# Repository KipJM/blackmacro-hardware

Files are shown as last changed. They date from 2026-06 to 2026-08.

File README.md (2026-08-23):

# BMacro V2
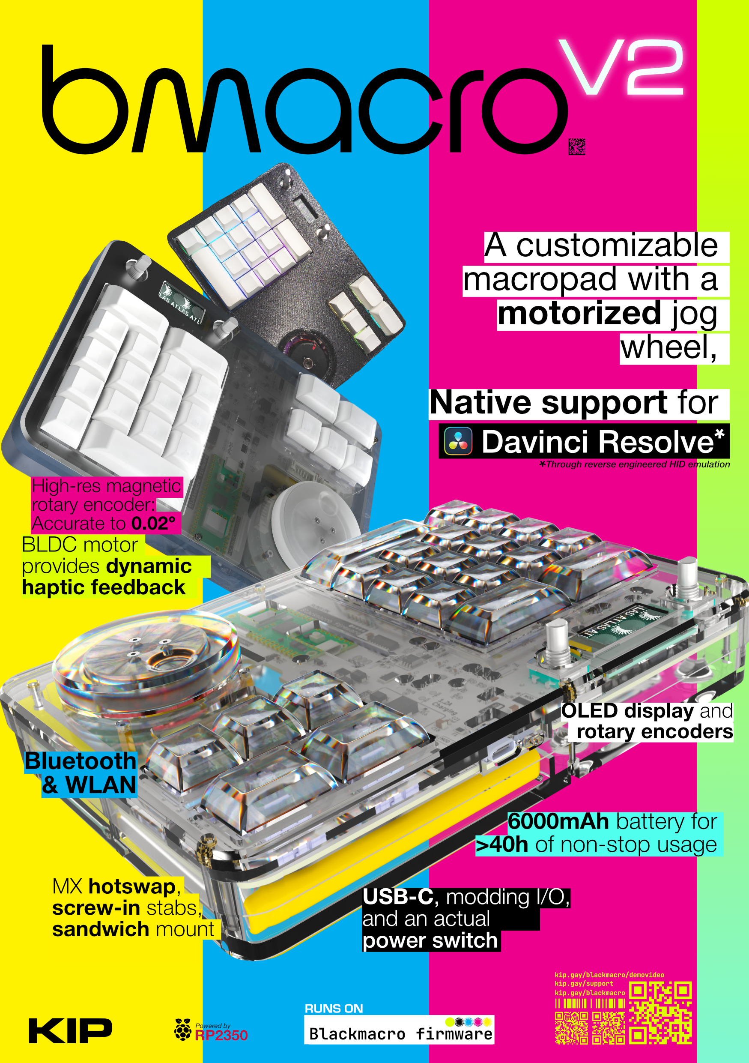
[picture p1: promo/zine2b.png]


> # This project took me over _*300*_ hours of work to create.
> Donations to my Ko-Fi would be highly appreciated! It'll support me to continue updating my project and its firmware.
> 
> ### **You can support me at: https://kip.gay/support**

> Additionally, if you're perhaps interested in purchasing an assembled blackmacro keyboard, let me know in github issues!
> I'd love to see if it's possible to mass manufacture this thing to bring costs down.

A bluetooth-capable condensed macro keyboard with a motorized jog wheel, powered by a Raspberry Pi Pico 2W.

### This keyboard's jog wheel gives you smooth analog control over the Davinci Resolve playhead, which is only possible on this keyboard or the official Speed Editor.

Supports remappable keyboard input, smooth scrolling, MIDI input, or
driverless Davinci Resolve control through reverse-engineered HID emulation.

Each key is a hotswappable MX-style plateless switch with a reverse-mounted addressable RGB LED.
The 2u and 1.5u in/out clips/timeline keys also feature screw-mount stabilizers.

The jog wheel is driven by a FOC-controlled brushless DC motor and a magnetic angle encoder, allowing for user-definable
haptic feedback and buttery smooth scrolling when working through your video timeline.

**It costs ~180 USD to create one blackmacro keyboard if not using CNC.**

> #### This hardware is purpose-built for blackmacro-lib. For more information on the purpose of this device, see [blackmacro-lib](https://github.com/KipJM/blackmacro-lib).
> #### For the firmware of this device, see [blackmacro-firmware](https://github.com/KipJM/blackmacro-firmware).

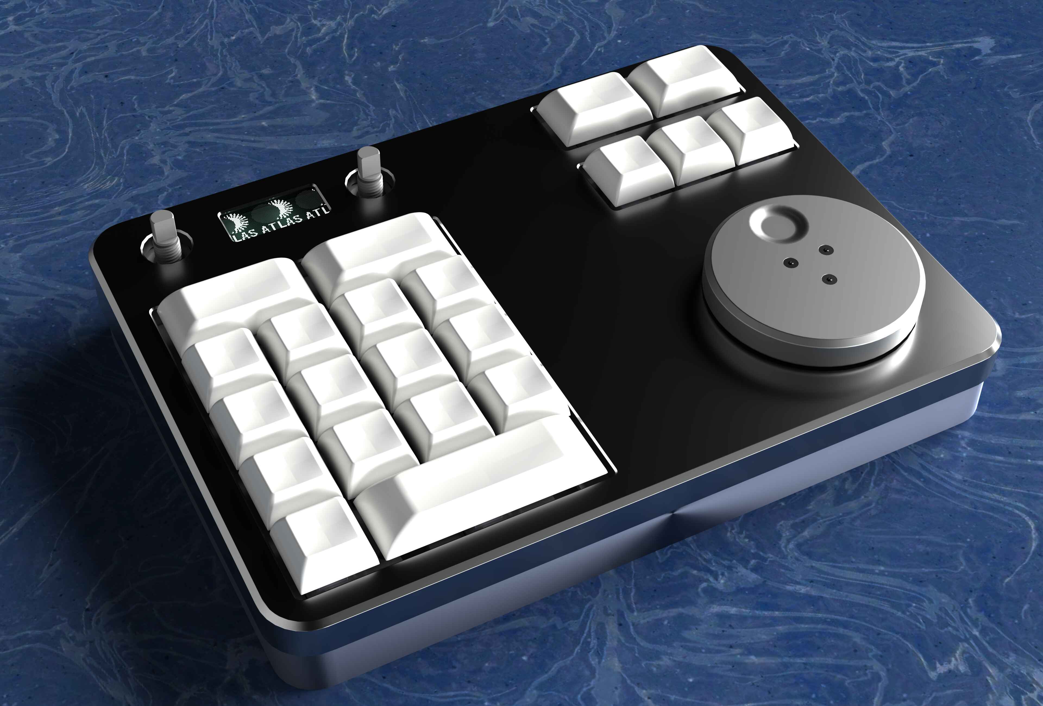
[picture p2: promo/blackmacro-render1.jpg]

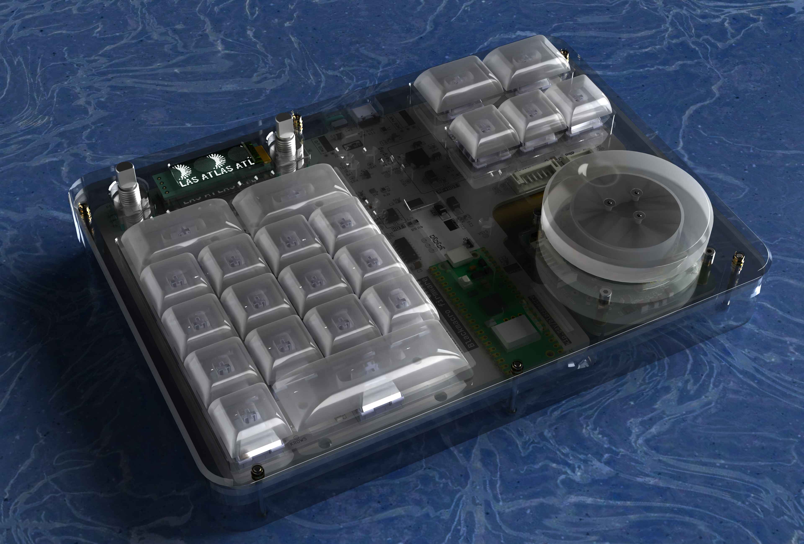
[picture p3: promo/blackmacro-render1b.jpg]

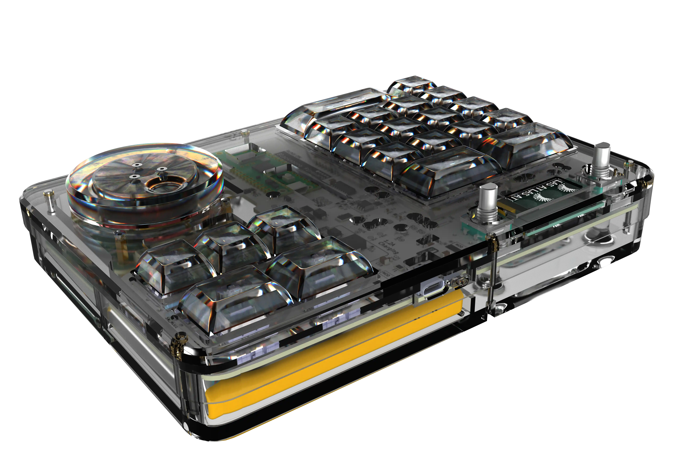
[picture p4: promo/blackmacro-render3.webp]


> ### Name
> Help me pick a better name for this thing...

> You're looking at version 2. For V1 archive switch to branch v1.

# Why
Bmacro (or Blackmacro keyboard) is designed to be an open source, leaner, customizable, and more powerful alternative to the Davinci Resolve Speed Editor keyboard.

The original speed editor features keys that aren't remappable and is locked to the Davinci Resolve software, only some of its keys feaure single-color LEDs,
plus its jog wheel doesn't feature the mechanical clutch found on its bigger Editor Keyboard sibling. Bmacro improves on this in almost every way, then adding
additional knobs to expand its input capabilities! While it features less keys than the Speed Editor, each key is software remappable so you can have the inputs you actually need.
Inspired by the smartknob project, the jog wheel is replaced with a Field Oriented Controlled BLDC motor, not only allowing it to emulate a mechanical clutch, but also other [software-defined haptic feedback!](https://www.youtube.com/watch?v=J9192DfZplk)

Running the FOSS Blackmacro firmware, bmacro can not only fully emulate all features of the Speed Editor and interface with Davinci Resolve without the need for any drivers,
but it can also emulate other inputs, such as smooth scrolling, volume control, generic macropad, or MIDI input. Through the rotary encoder knob and the 0.91 inch OLED screen, you can switch between these modes.

Demo Video (https://www.youtube.com/watch?v=7sNWoTAWSeA)

# License
This project is licensed under the CERN Open Hardware Licence Version 2 - Weakly Reciprocal.

Copyright © KIP 2026.

**Any individual or corporate entity are strictly forbidden from training "generative AI" analytical neural networks (LLMs, etc.) on contents of this project.**

Selling fabricated hardware of this project as-is is strongly discouraged. Please reach out to me at [kip@kip.gay](mailto://kip@kip.gay).

# Features
- 21 MX-style south-facing hotswap sockets
- Fully addressable RGB backlight LED for each key
- 2 Alps-style rotary encoder with click input

- High fidelity jog dial powered by the MT6701 magnetic encoder, **accurate to 0.02 degrees**
- BLDC Motorized jog dial power by the TMC6300 motor driver, providing dynamic haptic feedback

- 6000mAh built-in battery, enough battery life for over 40 hours of **non-stop usage**
- Efficient power management
- Seamless power handoff when disconnecting/connecting USB

- **An actual power switch**
- USB-Type C input

- Sandwich-mount style case
- Cool PCB designs :)

- Powered by Raspberry Pi Pico 2W
- Original moddable firmware
- Native compatibility with Davinci Resolve (unofficial)
- Wide HID emulation capability, can also act as a mouse/keyboard/game controller/MIDI device
- Bluetooth & WLAN capable

# Folder Structure
This project is made up of two PCBs and a case. The PCB project and production files can be found inside each board's folder within PCB/. For Bill of Materials, please also see each board's respective bom/bom.csv.

# BOM
You can find a merged BOM of all parts at the root of this project, however for more info please see the board-specific BOMs. The master BOM might be incorrect.

Bill of materials are separated by boards, please see `bom.csv` within the the bom/ folder of each PCB. `Quantity` is the amount of that part used on this board, `Actual Total Cost` represent the amount I spent to satisfy the entire project's needs on that particular component, so it's influenced by my inventory, regional price differences, and discounts, so it should only serve as a rough estimate of how much the project's gonna cost you. If "-" is in place of the price entry, it means the price has already been listed elsewhere (or on another BOM).

Also note that any `LCSC #` values you find in the KiCAD project are likely incorrect!

3D printed part cost is calculated based on JLC3DP.

# Electronics
The project is made up of two boards:
- The dial board (aka the jog wheel board)
- The base board (aka the keyboard board)

Use each PCB's respective `{name}_bom.csv` for purchasing parts, I recommend using the interactive BOM HTML for part placement reference.

## Dial board
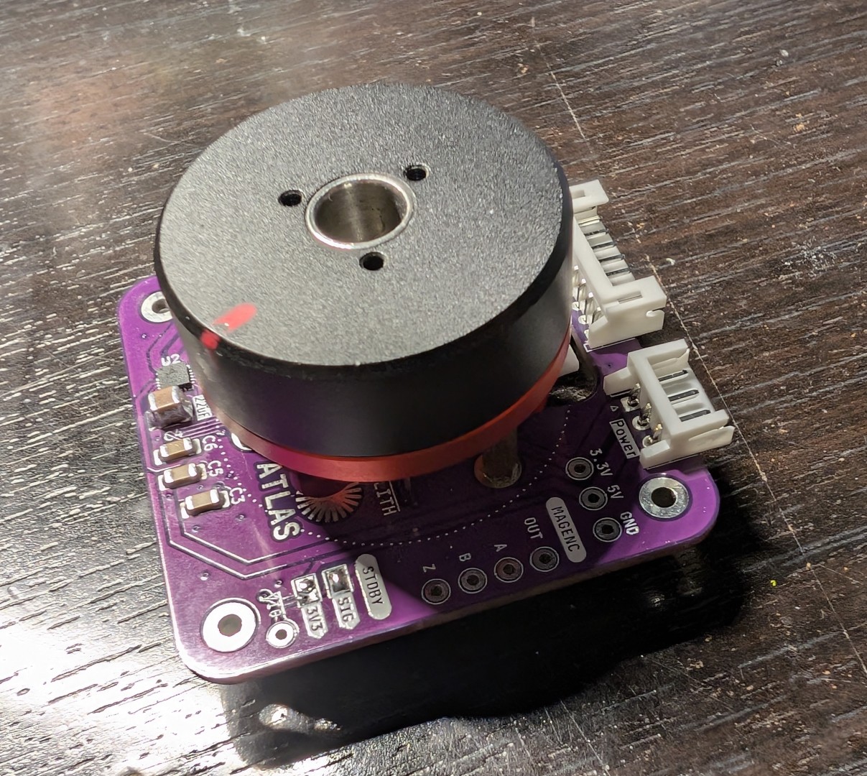
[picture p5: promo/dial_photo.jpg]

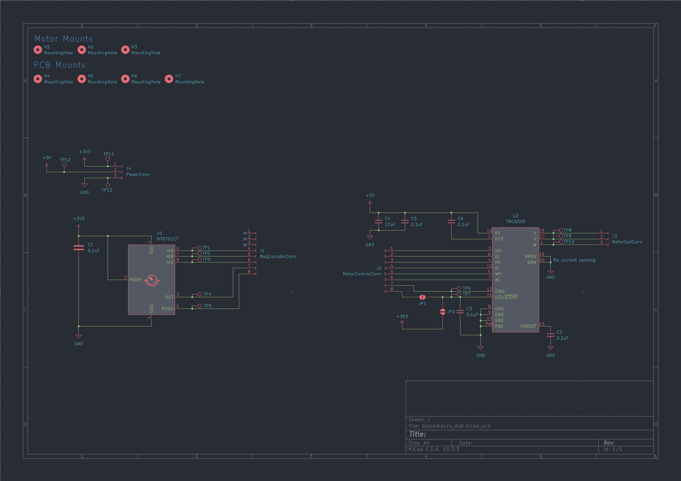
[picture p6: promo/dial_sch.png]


| | |
|:---:|:---:|
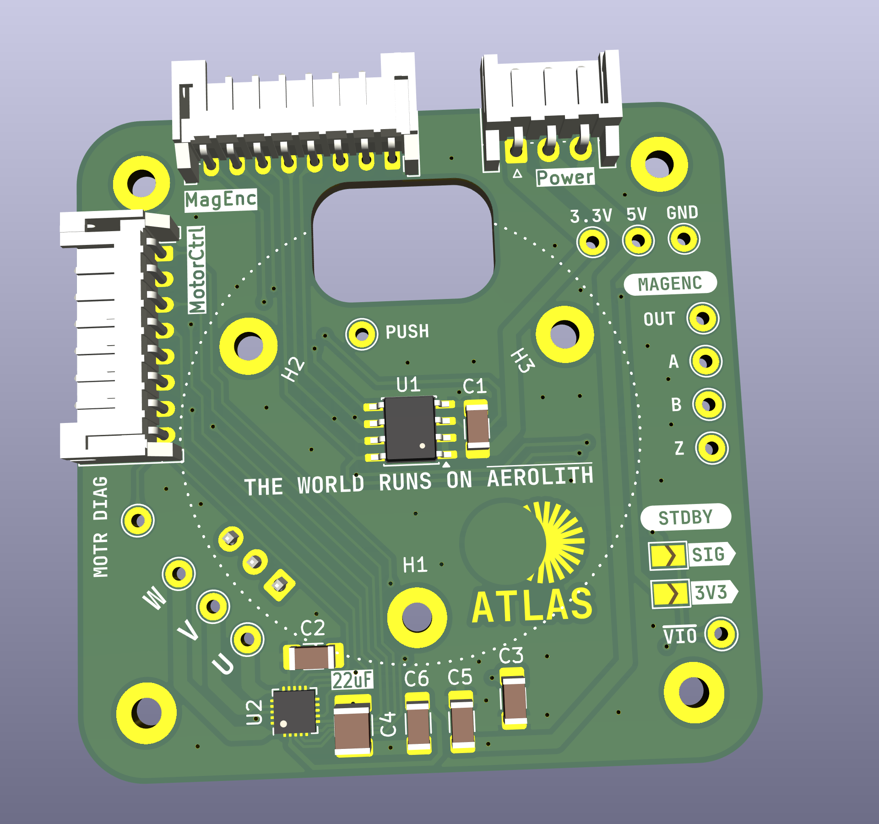
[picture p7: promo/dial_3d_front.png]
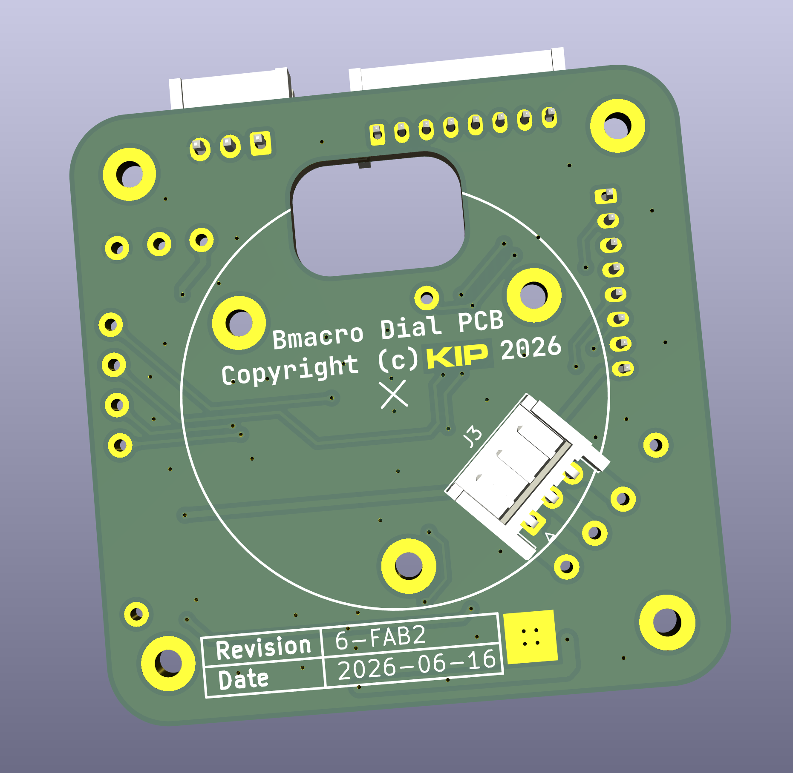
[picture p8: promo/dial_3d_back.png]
|    |    |
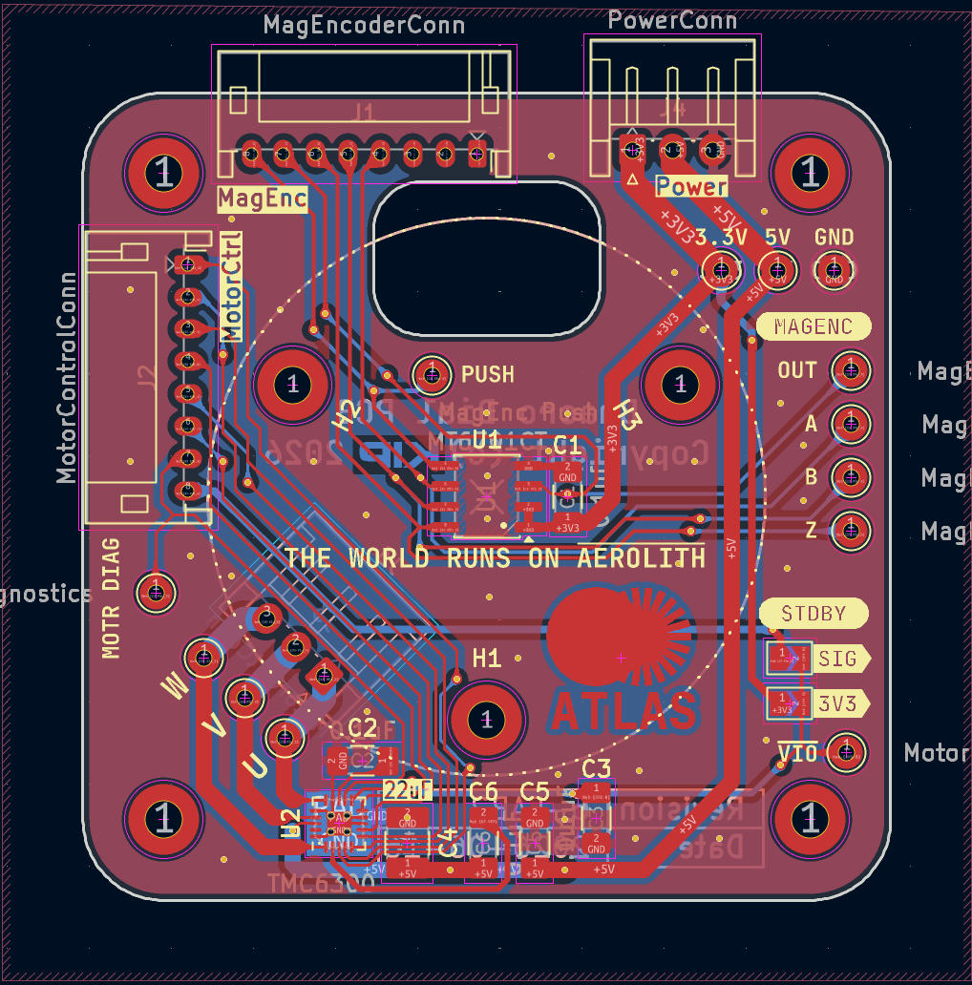
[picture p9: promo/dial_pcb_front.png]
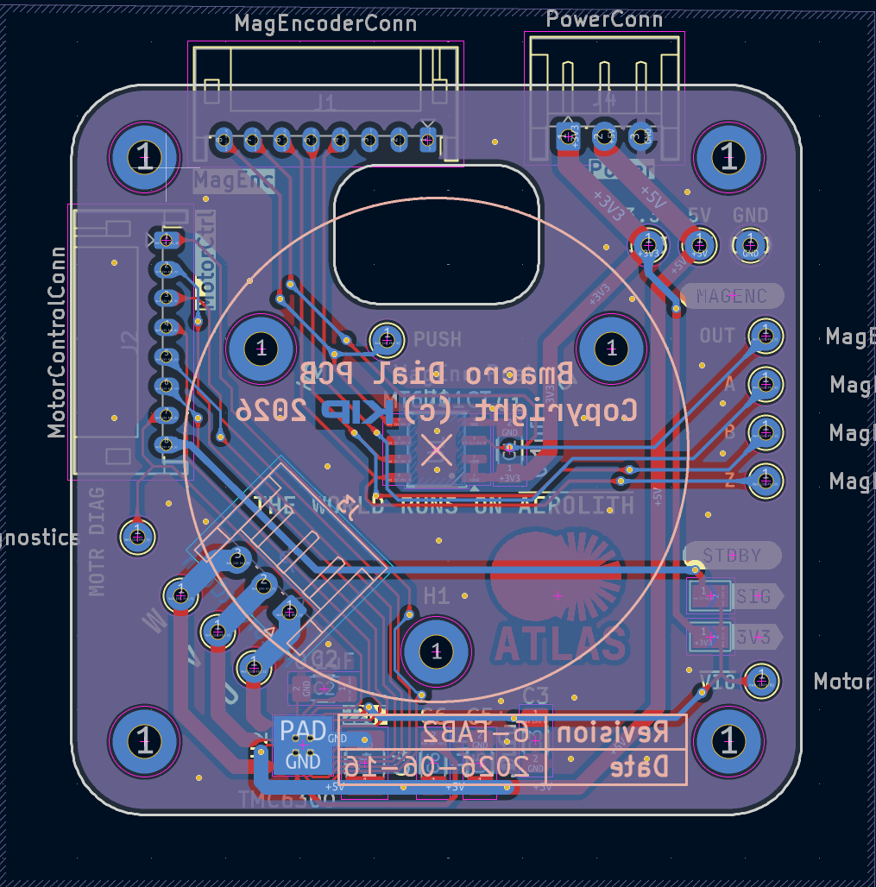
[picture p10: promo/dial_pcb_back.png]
|  |  |

The motor driver, TMC6300, is only available in QFN packages. I recommend purchasing a stencil along with your PCB (at least get solder paste and flux).
You should get a cable along with your motor terminated on one side as a small JST male connector, you'll need to crimp a 3-pin JST EH connector on the other side.

Use standoffs and flathead (as in the head is flat) M2 screws to attach the motor to the PCB. The standoffs length is purposely chosen so the motor's builtin diametric magnet would be
perfectly aligned on top of the MT6701 magnetic encoder with the correct air gap. Unfortunately this means the push button functionality is not present, but you can
add this feature back by replacing the standoffs with stiff springs.

There are two solder jumpers letting you select how the motor controller chip should be activated. Use a soldering iron and a bit of solder, swipe right to bridge the connection, swipe left to break the connection. **You should only have one connected at a time.**
I recommend setting it to SIG, if set to 3V3, the motor driver will stay on as long as there's power, and the MCU cannot command it to go to sleep through the SIG pin.

## Base board
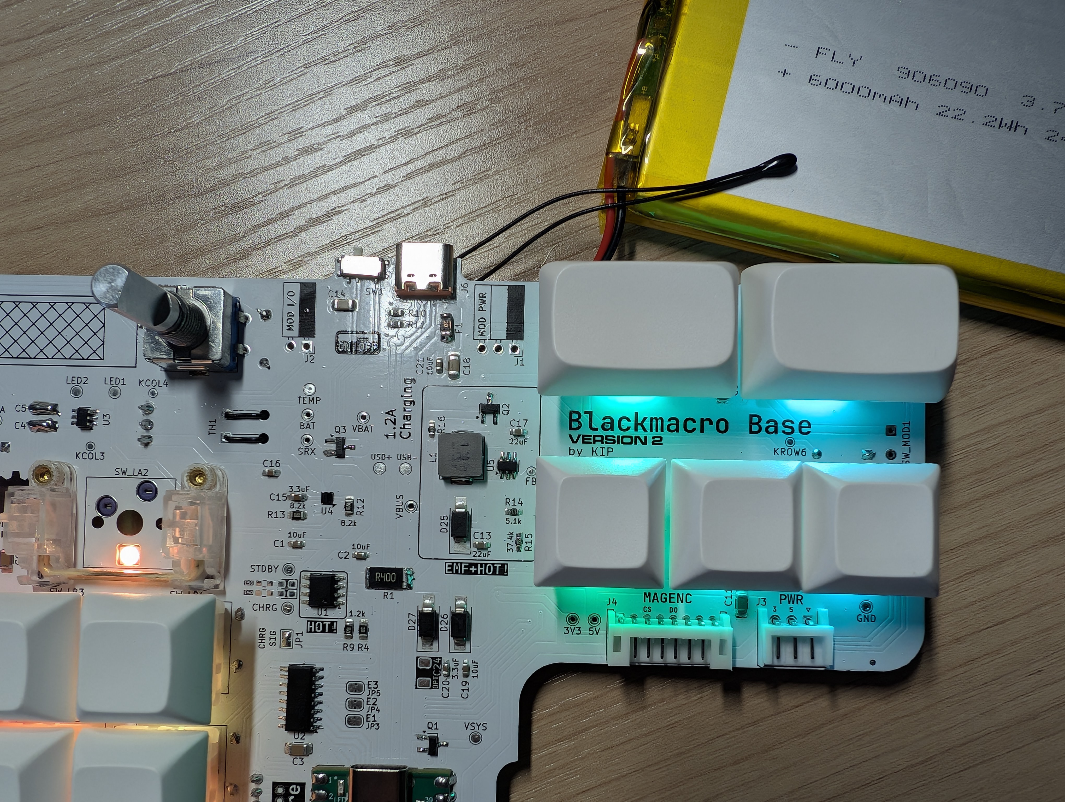
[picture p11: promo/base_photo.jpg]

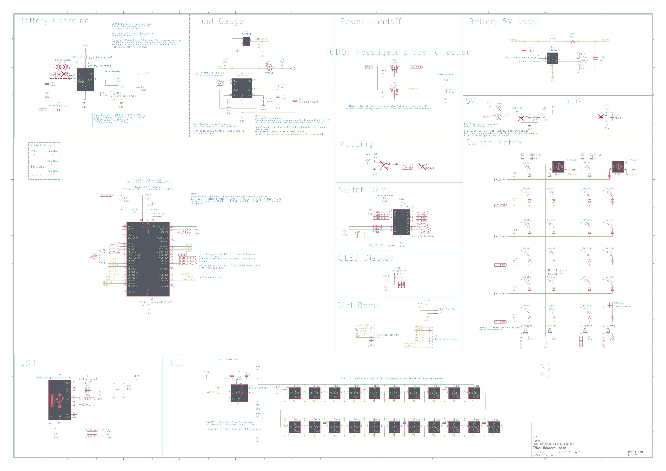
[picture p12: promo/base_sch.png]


| | |
|:---:|:---:|
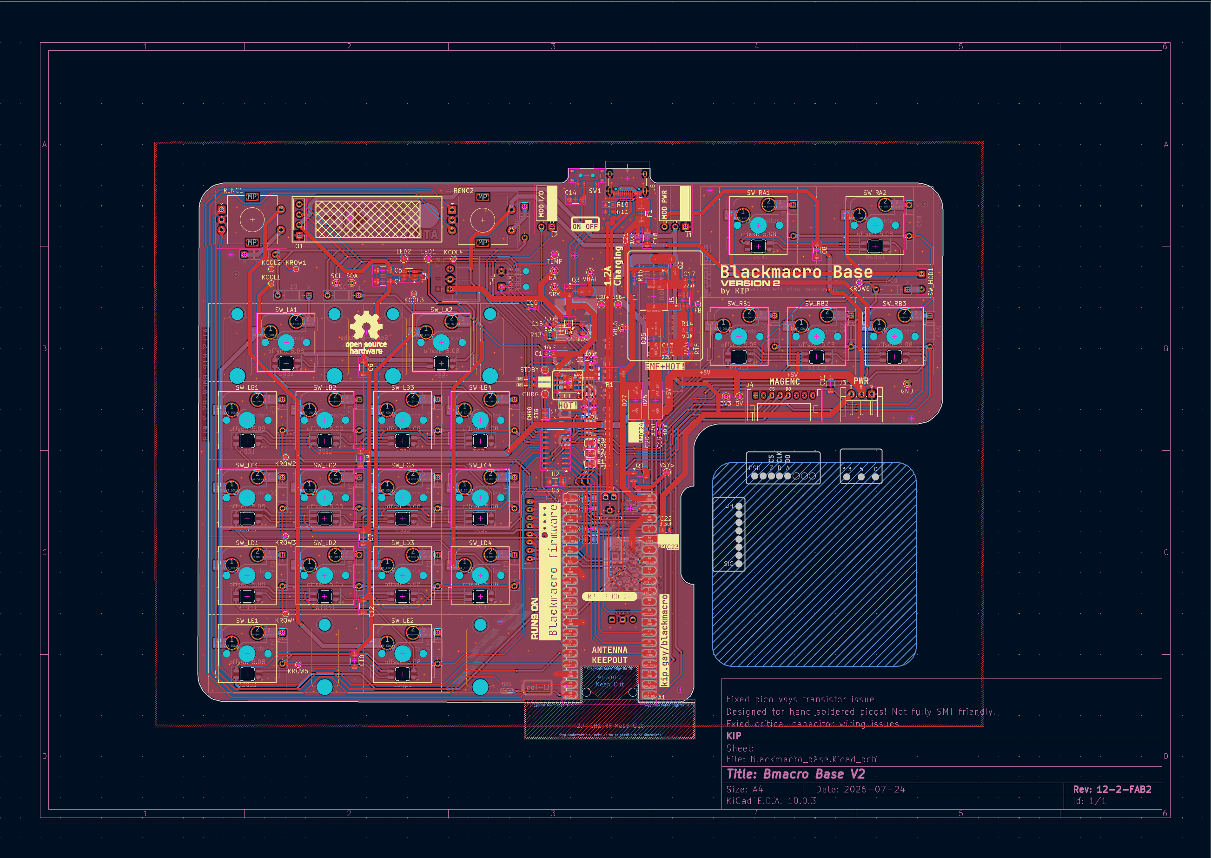
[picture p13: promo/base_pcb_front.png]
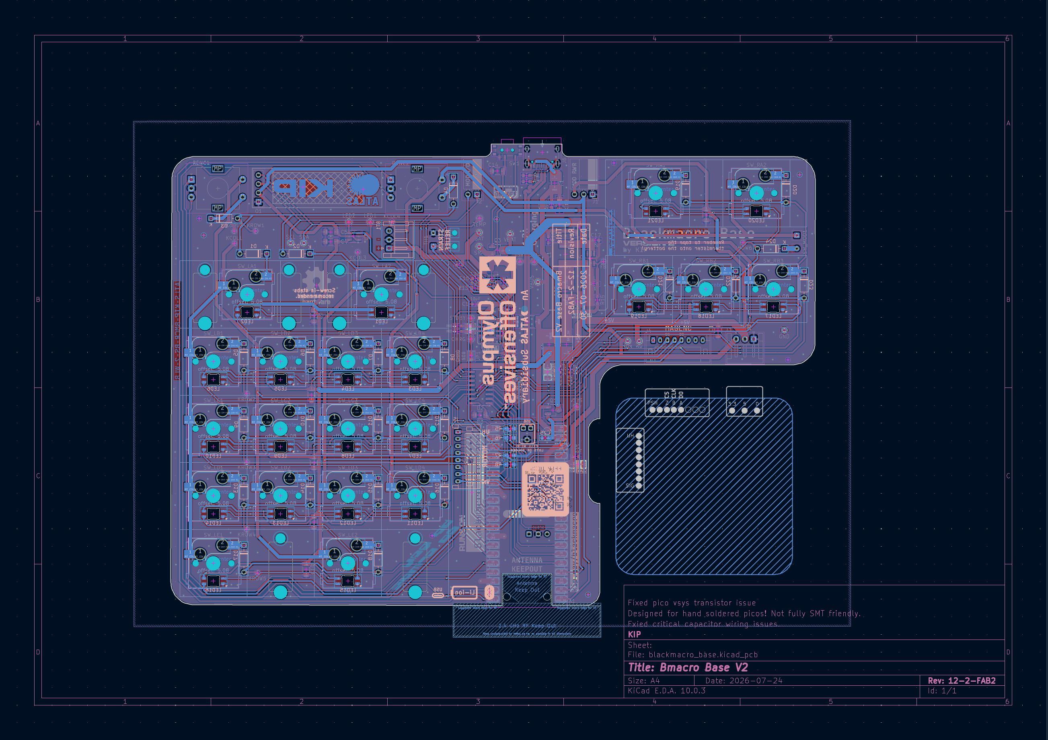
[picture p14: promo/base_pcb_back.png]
|   |  |
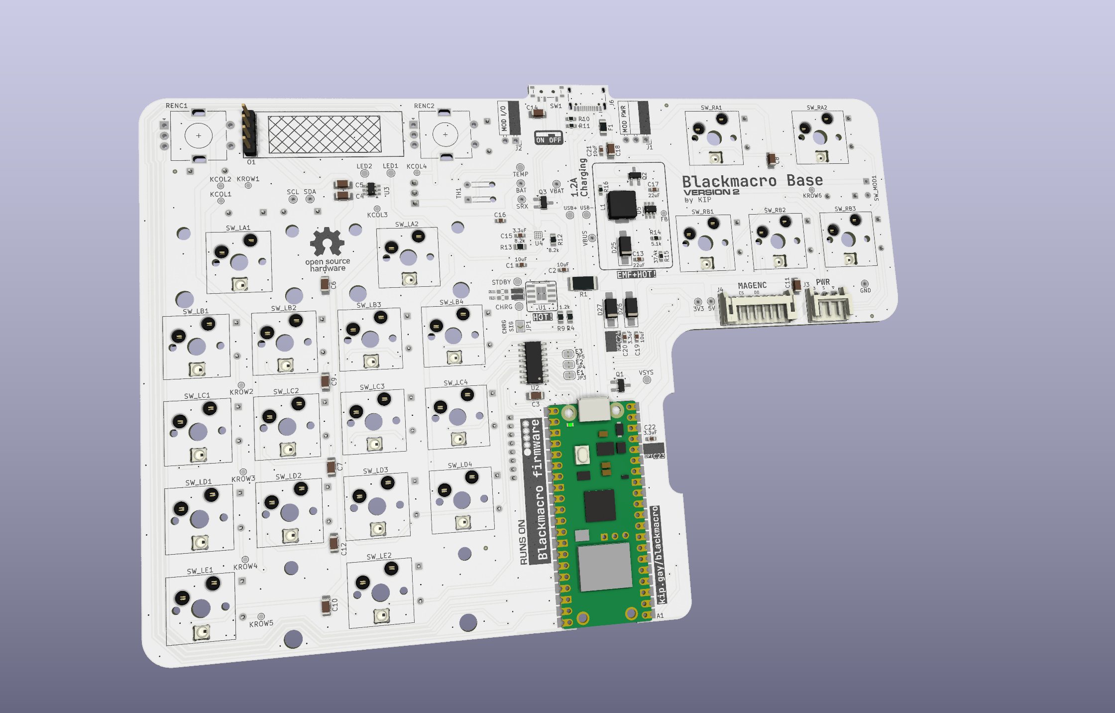
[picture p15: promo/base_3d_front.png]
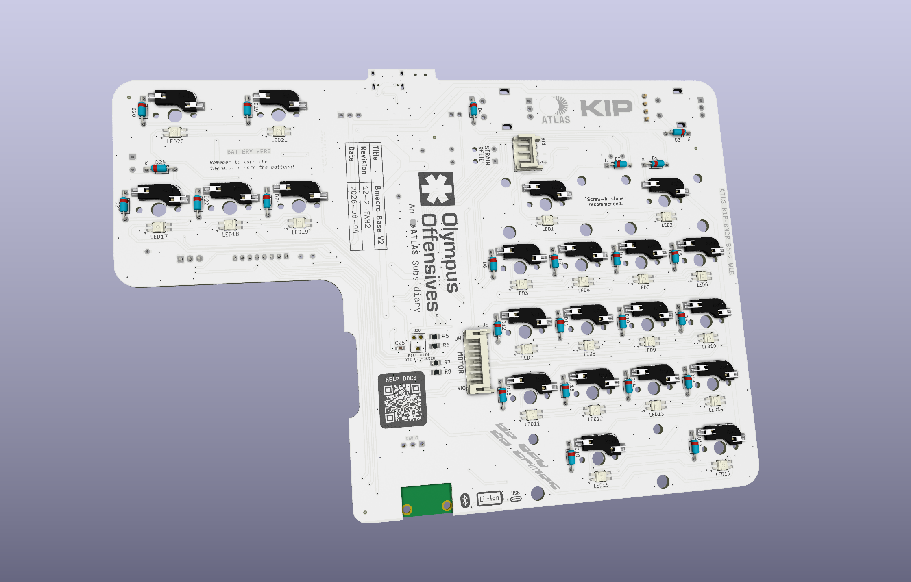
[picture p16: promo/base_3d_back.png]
|   |    |

The base board is designed for hotswap connectors, but the holes are plated so you technically can directly solder switches onto it.

> ## Make sure you're building the 11-2-fab2 or later versions of this board!
> 10-2-fab1, the initially fabricated version that I built this project on, includes a critical error with the logic shifter circuitry.
> If you built the 10-2-fab1 version, you'll have to remove the `C4` and `C5` capacitors and replace them with solder bridges, otherwise your LEDs won't work.

A few notable features of the base board:
- **The cutout:** the board is designed to work with a Pi Pico 2W. For the best Bluetooth performance,
the pcb is cut out under the pico's antenna.
- **Battery charging:** This board uses the HTP4056, a modified clone of the TP4056 that allows for a higher charging current.
- **USB**: The pico features three rectangular testpoints on the bottom for USB connections. To make this board hand solderable,
These TPs are connected through THTs. After soldering the pico to the board, fill the THTs with solder (use more than you would), then verify with a multimeter
that they have been soldered correctly. **This also means that the board is not full-SMT friendly. Beware!**
- **Stabilizers:** Screw-in stabilizers recommended. You'll need to get two 2U and one 3U steel wire.
- **Keycaps:** **16** 1U, **2** 1.5U, **2** 2U, **1** 3U.
- **MagEnc:** Most pins are unused. However, for extra rigidity terminate the other wires too!
- **Battery:** You'll have to terminate the battery leads into the JST connector. The top pin is unused.
- **Battery temperature probe:** For the NTC temperature probe, route its wires through the strain-relief so the leads
are inserted from the top of the board, and the probe should be at the bottom. Then tape the probe onto the battery with heat-resistant tape (safe at 40C min.)

I recommend fabbing the base PCB in white for better RGB LED performance. _(plus it just looks better)_

This board includes a 16-pin type-C port, DSBGA-9, and ESOP, which are hard to solder and requires a hotplate. I therefore recommend
getting partial PCBA for them and basic components.

When making the board interconnect cables, MAKE SURE the polarity is correct so that the correct pins are connected.
You can see silkscreen showing reference pins.

A stencil or hotplate is not required if you got partial PCBA, but flux/solder paste is highly recommended.

# 3D printed parts
Parts list:
- Case bottom
- Case top
- Plate
- (optional) jog wheel

> #### INFO!
> I do not recommmend printing the case, especially the plate, using PLA+ or regular PLA,
> It will sound very pingy!
>
> Instead, consider getting them fabricated using resin, laser-cut POM/Sheet metal, or CNC'd aluminium. 

# Case & Assembly
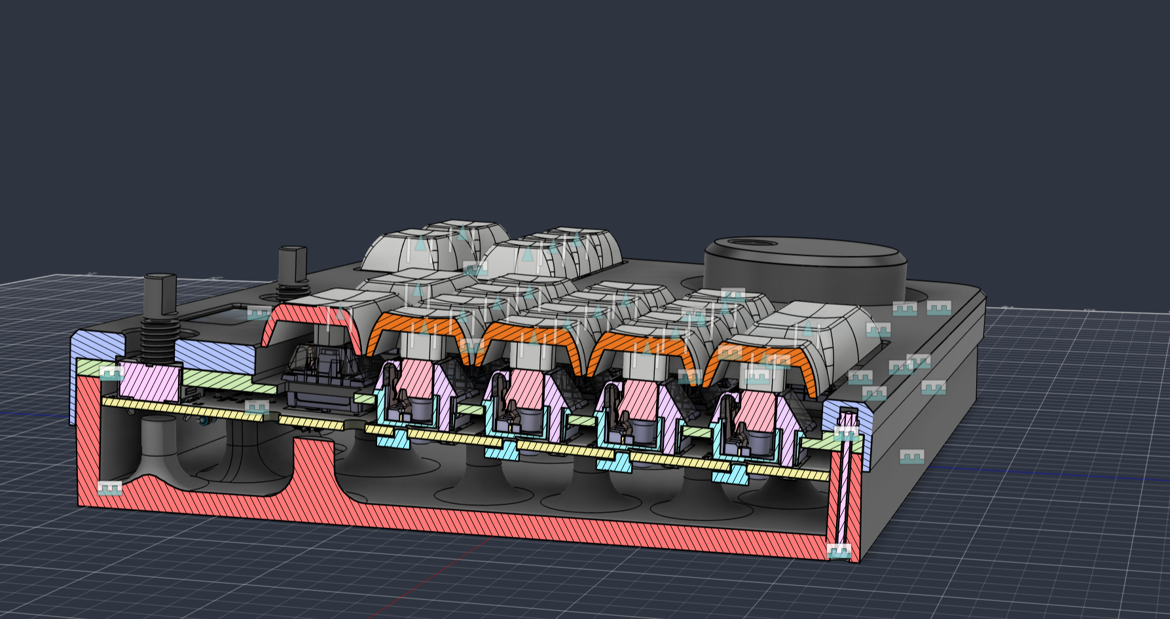
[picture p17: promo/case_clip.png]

The case uses a sandwich-style mechanical keyboard mounting setup, with special modifications for the the jog wheel.

The `Assembly V2` Fusion 360 archive file contains all mounting details, including fasteners and heat-set inserts. Use
that as assembly reference.

### Switches
Should be the same as any mechanical keyboard. Search online for mech keyboard assembly guides.

### Heat-set Inserts, Standoffs, and Screws
This project uses two types of M2 screws, one type of M2 standoff, and one type of M2 heat-set inserts.

The specifications of each part is carefully chosen, make sure you get fasteners with the exact same specs.

### Battery
After taping the NTC temperature probe to the top side of the battery, apply double-sided foam tape
onto the battery compartment of the bottom case. Stick the battery onto the tape, and apply padding onto the compartment
walls if necessary.

### Assembly Order
After the heat-set inserts are installed, assemble the device in the following order:
1. I recommend driving the screws through the holes once before to drive out any excess support material.
2. Install screw-mounted stabs onto the PCB
3. Assemble all switches onto the plate
4. Tape the battery to the bottom case
5. install the dial board onto the case using standoffs
6. connect the pcb to the battery
7. preconnect all interconnect cables onto the dial board, leaving the base-side hanging.
8. snap the plate onto the pcb, install the pcb into the bottom case
9. connect all interconnect cables
10. screw in the four dial board mounting screws on the plate
11. install the OLED display
12. install the top case
13. screw in all six screws from the bottom, stop when the case is sealed shut.

### Sound
If printed out of PLA+, the keyboard will sound very pingy and hollow when assembled.
Fill the cavity in the case with foam, and consider doing tape/polyfil mods.

### Jog wheel
The jog wheel is designed to be CNC machined.
Use countersunk screws to install the dial onto the motor.

# The Motor
Unfortunately, there is no information on the manufacturer or datasheet of the motor used in this project. It seems to be from a leftover stock of motors that many small AliExpress vendors are reselling.

There should be a red ring at the bottom with three pin headers, two functionless 01x02 pins and one 01x03 UVW header. Make sure you're getting one that rotates 360 degrees with no limit mechanism.

The quality of the motor seems to vary, with some having low amounts of cogging, and some with none whatsoever. You may need to buy multiple to get one without cogging, but it's worth it (it's quite cheap anyways)!

The resellers use the same three images on their listings, lookup "2806 bldc" / "2806无刷电机" on AliExpress and you'll find a vendor.
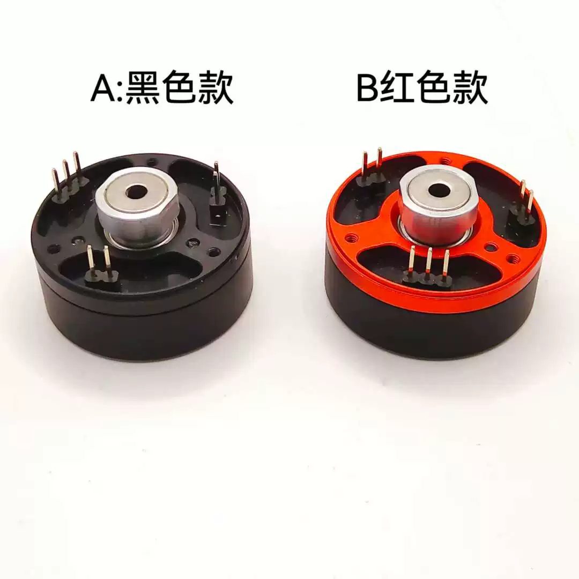
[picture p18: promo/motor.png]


# Firmware
Firmware is hosted at a separate repository. See https://github.com/KipJM/blackmacro-firmware.

# References
- https://github.com/shaise/DiSE
- https://github.com/scottbez1/smartknob
- https://github.com/dmcke5/Hapticpad

---

This project is not affiliated with or endorsed by Blackmagicdesign and Davinci Resolve.

Promo images rendered in Blender Cycles with openimagedenoise, please excuse any denoising artifacts. Yes the images are 8k and like 5mB, no I'm not sorry.

Davinci Resolve Compatibility is achieved through my project [blackmacro-lib](https://github.com/KipJM/blackmacro-lib).
It emulates a Speed Editor keyboard's HID protocols without decompilation of any blackmagic software/firmware.

Bmacro _(a.k.a. Blackmacro keyboard)_ is a fully original electronics hardware designed and fabricated by me, **KIP**. I am licensing this project under the CERN Open Hardware License Version 2 - Weakly Reciprocal. I reserve its copyright and the right to sell this hardware and its designs.

_Copyright © 2026_ **KIP**

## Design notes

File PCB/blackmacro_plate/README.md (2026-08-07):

# THIS IS NOT A REAL PCB! DO NOT FABRICATE THIS FILE!!!!!!!!
blackmacro_plate is a proxy project cloned from blackmacro_base so I can generate a vector file for the keyswitch plate with accurate layouts.  
**AGAIN, DO NOT TREAT THIS AS A PCB!! IT IS NOT DESIGNED TO BE MANUFACTURED EVEN AS A PCB PLATE!! 3D PRINT ONLY!!**

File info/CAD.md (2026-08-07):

case top key radius: 1.25mm
tilt angle: 2.5deg
m2x3x3.5 heatset

1 + 1.5 + 0.5

3 + 3 + 15 
M2x22 screws, head diameter 3.2mm 1.3 thick

22.5 max

26
20 + 4 = 24 - 2 = 22

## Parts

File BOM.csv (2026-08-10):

References | Value | Footprint | Quantity | Part | Link | Actual Total Cost (CNY)
C3, C4, C5, C6, C7, C8, C9, C10, C11, C12, C14, C18 | 0.1uF | C_1206_3216Metric_Pad1.33x1.80mm_HandSolder | 12 | CL31B104KBCNNNC | (PCBA) | 4.08
C1, C2, C19, C21, C25 | 10uF | C_0603_1608Metric_Pad1.08x0.95mm_HandSolder | 5 | CL10A106KP8NNNC | (PCBA) | 2.0080
C15, C16, C20, C22 | 3.3uF | C_0603_1608Metric_Pad1.08x0.95mm_HandSolder | 4 | CL10A335KP8NNNC | https://item.szlcsc.com/52425.html | 3.13
C13, C17 | 22uF | C_0603_1608Metric_Pad1.08x0.95mm_HandSolder | 2 | CL10A226MQ8NRNC | (PCBA) | 1.0760
C23, C24 | OPTIONAL | C_1206_3216Metric_Pad1.33x1.80mm_HandSolder | 2 | N/A | N/A | N/A
R5, R6, R7, R8, R12, R13 | 8.2k | R_0805_2012Metric_Pad1.20x1.40mm_HandSolder | 6 | 0805W8F8201T5E | https://item.szlcsc.com/18516.html | 2.3
R10, R11, R14 | 5.1k | R_0603_1608Metric_Pad0.98x0.95mm_HandSolder | 3 | 0603WAF5101T5E | (PCBA) | 0.3108
R4, R9 | 1.2k | R_0805_2012Metric_Pad1.20x1.40mm_HandSolder | 2 | 0805W8F1201T5E | (PCBA) | 0.1040
R1 | 0.4 | R_2512_6332Metric_Pad1.40x3.35mm_HandSolder | 1 | 25121WF400LT4E | https://item.szlcsc.com/414511.html | 2.57
R15 | 37.4k | R_0603_1608Metric_Pad0.98x0.95mm_HandSolder | 1 | FRC0603F3742TS | https://item.szlcsc.com/3279313.html | 1.34
R16 | 100k | R_0603_1608Metric_Pad0.98x0.95mm_HandSolder | 1 | 0603WAF1003T5E | (PCBA) | 0.0260
L1 | 4.7uH | L_Changjiang_FXL0630 | 1 | FXL0630-4R7-M | https://item.szlcsc.com/178603.html | 2.93
D1, D2, D3, D4, D5, D6, D7, D8, D9, D10, D11, D12, D13, D14, D15, D16, D17, D18, D19, D20, D21, D22, D23, D24 | 1N4148WS | D_DO-35_SOD27_P7.62mm_Horizontal | 24 | 1N4148WS | N/A, must be THT | 3.5
D25, D27 | SS54 | D_SMA_Handsoldering | 2 | SS54 | (PCBA) | 1.7160
D26 | SS54_optional (actually required) | D_SMA_Handsoldering | 1 | SS54 | (PCBA) | -
U1 | HTP4056-42-ESOP8 | SOIC-8-1EP_3.9x4.9mm_P1.27mm_EP2.41x3.3mm_ThermalVias | 1 | HTP4056 | (PCBA) | 20.4760
U2 | 74HC238 | SOIC-16_3.9x9.9mm_P1.27mm | 1 | 74HC238D 653 | https://item.szlcsc.com/6071.html | 3.67
U3 | SN74LVC1T45DBV | SOT-23-6_Handsoldering | 1 | SN74LVC1T45DBVR | https://item.szlcsc.com/8320.html | 2.76
U4 | BQ27427 | Texas_DSBGA-9_1.62x1.58mm_Layout3x3_P0.5mm | 1 | BQ27427YZFR | (PCBA) | 35.8000
U5 | MT3608L | SOT-23-6_Handsoldering | 1 | MT3608L | https://item.szlcsc.com/3276649.html | 0.92
F1 | hold=2, trip=3.5 | Fuse_1206_3216Metric_Pad1.42x1.75mm_HandSolder | 1 | SMD1206-200-12 | https://item.szlcsc.com/48798740.html | 2.47
SW1 | SW_SPDT | SW_SPDT_Shouhan_MSK12C02 | 1 | MSK12C02 | https://item.szlcsc.com/427897.html | 3.59
A1 | RaspberryPi_Pico_2W | RaspberryPi_Pico_W_SMD_THTdebug | 1 | LOBOROBO pico 2W Type-C clone board | N/A, any Pico 2W is fine | 46
LED1, LED2, LED3, LED4, LED5, LED6, LED7, LED8, LED9, LED10, LED11, LED12, LED13, LED14, LED15, LED16, LED17, LED18, LED19, LED20, LED21 | SK6812MINI-E | LED_MX_6028R | 21 | SK6812MINI-E | https://item.szlcsc.com/5773397.html | 2.69
SW_LB1, SW_LB2, SW_LB3, SW_LB4, SW_LC1, SW_LC2, SW_LC3, SW_LC4, SW_LD1, SW_LD2, SW_LD3, SW_LD4, SW_LE1, SW_RB1, SW_RB2, SW_RB3, SW_LA1, SW_LA2, SW_RA1, SW_RA2, SW_LE2 | SW_Push_45deg | SW_Hotswap_Kailh_MX_Plated_1.00u | 21 | CPG151101S11-16 | https://item.szlcsc.com/43288200.html | 8.22
SW_LB3, SW_LB4, SW_LC1, SW_LC2, SW_LC3, SW_LC4, SW_LD1, SW_LD2, SW_LD3, SW_LD4, SW_LE1, SW_RB1, SW_RB2, SW_RB3, SW_LA1, SW_LA2 | SW_Push_45deg | SW_Hotswap_Kailh_MX_Plated_1.00u | 16 | Gateron KS-3 Milky Pro Yellow Switch (5-pin) | N/A | 19.6
SW_LA1, SW_LA2, SW_LE2, SW_RA1, SW_RA2 | SW_Push_45deg | SW_Hotswap_Kailh_MX_Plated_?u | 4 | Gateron G Pro Brown Switch (5-pin) | N/A | 10.64
Q1, Q2, Q3 | AO3415 | SOT-23_Handsoldering | 3 | AO3415 | https://item.szlcsc.com/192491.html | 3.21
RENC1, RENC2 | RotaryEncoder_Switch | RotaryEncoder_Alps_EC11E-Switch_Vertical_H20mm | 2 | EC11 | N/A | 3.2
ST_LA1, ST_LA2 | 2u | STAB_MX_2u | 2 | Screw-in stabilizers kit, 2U*4, 6.25U*1 | N/A | 19.9
BT1 | FLY.906090.6000 | N/A | 1 | FLY.906090.6000 | https://item.szlcsc.com/mro/6029072.html | 25.72
O1 | OLED_Display | PinHeader_1x04_P2.54mm_Vertical | 1 | 0.91in i2C OLED display, check schematics for pin order | N/A | 8.33
ST_LE1 | 3u | STAB_MX_3u | 1 | 3U stab wire | N/A | 12
TH1 | 10k, 43C=4.791k | SolderWire-0.127sqmm_1x02_P3.7mm_D0.48mm_OD1mm_Relief | 1 | MF52D 103F3950-100 | https://item.szlcsc.com/372743.html | 2.99
J3, BT1 | N/A | JST_EH_S3B-EH_1x03_P2.50mm_Horizontal | 2 | EH-3AWD | https://item.szlcsc.com/23924585.html | -
J4, J5 | N/A | JST_PH_S8B-PH-K_1x08_P2.00mm_Horizontal | 2 | PH-8AWD | https://item.szlcsc.com/21938977.html | -
J6 | USB_C_Receptacle_USB2.0_16P | USB_C_Receptacle_HCTL_HC-TYPE-C-16P-01A | 1 | HC-TYPE-C-16P-01A-O | (PCBA) | 21.8620
N/A | PCB | N/A | 1 | blackmacro_base | N/A | 87.49
N/A | SMT Assembly | N/A | 1 | blackmacro_base SMT | N/A | 137.44
SW_LB3, SW_LB4, SW_LC1, SW_LC2, SW_LC3, SW_LC4, SW_LD1, SW_LD2, SW_LD3, SW_LD4, SW_LE1, SW_RB1, SW_RB2, SW_RB3, SW_LA1, SW_LA2 | SW_Push_45deg | SW_Hotswap_Kailh_MX_Plated_1.00u | 16 | 1u XDA keycap | N/A | 25
SW_LA1, SW_LA2 | SW_Push_45deg | SW_Hotswap_Kailh_MX_Plated_2u | 2 | 2u XDA keycap | N/A | 8.74
SW_LE2 | SW_Push_45deg | SW_Hotswap_Kailh_MX_Plated_3u | 1 | 3u XDA keycap | N/A | 8.8
SW_RA1, SW_RA2 | SW_Push_45deg | SW_Hotswap_Kailh_MX_Plated_1.5u | 2 | 1.5u XDA keycap | N/A | 3.76
C1, C2, C3, C5, C6 | 0.1uF | C_1206_3216Metric_Pad1.33x1.80mm_HandSolder | 5 | CL31B104KBCNNNC | https://item.szlcsc.com/25237.html | 4.67
C4 | 22uF | C_1210_3225Metric_Pad1.33x2.70mm_HandSolder | 1 | CL32A226KAJNNNE | https://item.szlcsc.com/53320.html | 1.71
U1 | MT6701CT | SO-8_3.9x4.9mm_P1.27mm | 1 | MT6701CT-STD-R | https://item.szlcsc.com/3489938.html | 7.23
U2 | TMC6300 | QFN-20-1EP_3x3mm_P0.4mm_EP1.65x1.65mm_ThermalVias_LargerViaHoles | 1 | TMC6300-LA-T | https://item.szlcsc.com/6005328.html | 27.6
J1, J2 | N/A | JST_PH_S8B-PH-K_1x08_P2.00mm_Horizontal | 2 | PH-8AWD | https://item.szlcsc.com/21938977.html | 2.82
J3, J4 | N/A | JST_EH_S3B-EH_1x03_P2.50mm_Horizontal | 2 | EH-3AWD | https://item.szlcsc.com/23924585.html | 1.79
N/A | N/A | Plastic housing, JST EHR-3 | 2 | EHR-3 | https://item.szlcsc.com/173041.html | 3.69
N/A | N/A | Plastic housing, JST PHR-8 | 2 | PHR-8 | https://item.szlcsc.com/169298.html | 3.55
N/A | BLDC Motor | N/A | 1 | 2804 | Lookup 2804 on Aliexpress, resellers use the same three images (see README) | 14
N/A | PCB & Stencil | N/A | 1 | blackmacro_dial | N/A | 73
N/A | Standoffs | M2*9+4 | 3 | N/A | Search around on Aliexpress or your local hardware store | 1.99
N/A | Screws | M2*6 flat top philips | 7 | N/A | Search around on Aliexpress or your local hardware store. Flat top is not required but highly recommended! | 3.66
N/A | JST EH connector crimps | EH | 50 | EH-T | https://item.szlcsc.com/23924668.html | 2.69
N/A | JST BH connector Crimps | BH | 50 | BX-PH2.0-DZ | https://item.szlcsc.com/19218392.html | 2.18
N/A | N/A | Case Bottom | 1 | 3D Printed | (ATC is CNC, 10 piece discount price) | 2,417.63
N/A | N/A | Case Top | 1 | 3D Printed | (ATC is CNC, 10 piece discount price) | 1432.58
N/A | N/A | Plate | 1 | Resin 3D Print/Steel plate | (ATC is CNC) | 283.59
N/A | N/A | Switch | 1 | Resin 3D Print | N/A | 6.7
N/A | N/A | Jog Wheel | 1 | CNC Aluminum | N/A | 137.48
N/A | N/A | M2*6 Screw | 3 | M2*6, countersunk | N/A | 1.21
N/A | N/A | Foam | 1 | Poron foam 3mm;52cm*15cm | N/A | 15
N/A | N/A | M2*6 Screw | 3 | M2*6 philips | N/A | 2.66
N/A | N/A | M2*22 Screw | 6 | M2*22 philips | N/A | 1.83
N/A | N/A | M2*3*3.5 Heatset-insert | 9 | M2*3*3.5 Heatset-insert | N/A | 0.07
N/A | N/A | M3*3*4.5 Heatset-insert | 9 | M3*3*4.5 Heatset-insert | N/A | 1.84
 |  |  |  |  | TOTAL | 2985.54

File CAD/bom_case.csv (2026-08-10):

References | Value | Quantity | Part | Link | Actual Total Cost (CNY)
N/A | Case Bottom | 1 | 3D Printed/Aluminum CNC | (ATC is CNC, 10 piece discount price) | 2,417.63
N/A | Case Top | 1 | 3D Printed/Aluminum CNC | (ATC is CNC, 10 piece discount price) | 1432.58
N/A | Plate | 1 | Resin 3D Print/POM CNC | (ATC is CNC) | 283.59
N/A | Switch | 1 | Resin 3D Print | N/A | 6.7
N/A | Jog Wheel | 1 | CNC Aluminum | N/A | 137.48
N/A | M2*6 Screw | 3 | M2*6, countersunk | N/A | 1.21
N/A | Foam | 1 | Poron foam 3mm;52cm*15cm | N/A | 15
N/A | M2*6 Screw | 3 | M2*6 philips | N/A | 2.66
N/A | M2*22 Screw | 6 | M2*22 philips | N/A | 1.83
N/A | M2*3*3.5 Heatset-insert | 9 | M2*3*3.5 Heatset-insert | N/A | 0.07
N/A | M3*3*4.5 Heatset-insert | 9 | M3*3*4.5 Heatset-insert | N/A | 1.84
 |  |  |  | TOTAL | 2302.59

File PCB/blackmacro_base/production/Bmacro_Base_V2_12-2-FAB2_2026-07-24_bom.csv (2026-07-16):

Designator | Footprint | Quantity | Value | LCSC Part #
A1 | RaspberryPi_Pico_W_SMD_THTdebug | 1 | RaspberryPi_Pico_W
BT1 | JST_EH_S3B-EH_1x03_P2.50mm_Horizontal | 1 | FLY.906090.6000
C1, C19, C2, C21, C25 | 0603 | 5 | 10uF
C10, C11, C12, C14, C18, C3, C4, C5, C6, C7, C8, C9 | 1206 | 12 | 0.1uF
C13, C17 | 0603 | 2 | 22uF
C15, C16, C20, C22 | 0603 | 4 | 3.3uF
D1, D10, D11, D12, D13, D14, D15, D16, D17, D18, D19, D2, D20, D21, D22, D23, D24, D3, D4, D5, D6, D7, D8, D9 | D_DO-35_SOD27_P7.62mm_Horizontal | 24 | 1N4148WS
D25, D27 | D_SMA_Handsoldering | 2 | SS54
D26 | D_SMA_Handsoldering | 1 | SS54_optional
F1 | 1206 | 1 | hold=2, trip=3.5
J3 | JST_EH_S3B-EH_1x03_P2.50mm_Horizontal | 1 | Dial_PowerConn
J4 | JST_PH_S8B-PH-K_1x08_P2.00mm_Horizontal | 1 | Dial_MagEncoderConn
J5 | JST_PH_S8B-PH-K_1x08_P2.00mm_Horizontal | 1 | Dial_MotorControlConn
J6 | USB_C_Receptacle_HCTL_HC-TYPE-C-16P-01A | 1 | USB_C_Receptacle_USB2.0_16P
L1 | L_Changjiang_FXL0630 | 1 | 4.7uH
LED1, LED10, LED11, LED12, LED13, LED14, LED15, LED16, LED17, LED18, LED19, LED2, LED20, LED21, LED3, LED4, LED5, LED6, LED7, LED8, LED9 | LED_MX_6028R | 21 | SK6812MINI-E
O1 | PinHeader_1x04_P2.54mm_Vertical | 1 | OLED_Display
Q1, Q2, Q3 | SOT-23_Handsoldering | 3 | AO3415
R1 | 2512 | 1 | 0.4
R10, R11, R14 | 0603 | 3 | 5.1k
R12, R13, R5, R6, R7, R8 | 0805 | 6 | 8.2k
R15 | 0603 | 1 | 37.4k
R16 | 0603 | 1 | 100k
R4, R9 | 0805 | 2 | 1.2k
RENC1, RENC2 | RotaryEncoder_Alps_EC11E-Switch_Vertical_H20mm | 2 | RotaryEncoder_Switch
ST_LA1, ST_LA2 | STAB_MX_2u | 2 | 2u
ST_LE1 | STAB_MX_3u | 1 | 3u
SW1 | SW_SPDT_Shouhan_MSK12C02 | 1 | SW_SPDT
SW_LA1, SW_LA2 | SW_Hotswap_Kailh_MX_Plated_2.00u | 2 | SW_Push_45deg
SW_LB1, SW_LB2, SW_LB3, SW_LB4, SW_LC1, SW_LC2, SW_LC3, SW_LC4, SW_LD1, SW_LD2, SW_LD3, SW_LD4, SW_LE1, SW_RB1, SW_RB2, SW_RB3 | SW_Hotswap_Kailh_MX_Plated_1.00u | 16 | SW_Push_45deg
SW_LE2 | SW_Hotswap_Kailh_MX_Plated_3.00u | 1 | SW_Push_45deg
SW_MOD1 | SolderWire-0.127sqmm_1x02_P3.7mm_D0.48mm_OD1mm | 1 | Conn_01x02_Socket
SW_RA1, SW_RA2 | SW_Hotswap_Kailh_MX_Plated_1.50u | 2 | SW_Push_45deg
TH1 | SolderWire-0.127sqmm_1x02_P3.7mm_D0.48mm_OD1mm_Relief | 1 | 10k, 43C=4.791k
U1 | SOIC-8-1EP_3.9x4.9mm_P1.27mm_EP2.41x3.3mm_ThermalVias | 1 | HTP4056-42-ESOP8
U2 | SOIC-16_3.9x9.9mm_P1.27mm | 1 | 74HC238
U3 | SOT-23-6_Handsoldering | 1 | SN74LVC1T45DBV
U4 | Texas_DSBGA-9_1.62x1.58mm_Layout3x3_P0.5mm | 1 | BQ27427
U5 | SOT-23-6_Handsoldering | 1 | MT3608L

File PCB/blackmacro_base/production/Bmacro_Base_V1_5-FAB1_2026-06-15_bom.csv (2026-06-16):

Designator | Footprint | Quantity | Value | LCSC Part #
A1 | RaspberryPi_Pico_W_SMD_HandSolder | 1 | RaspberryPi_Pico_W
C10, C11, C12, C3, C4, C5, C6, C7, C8, C9 | 1206 | 10 | 0.1uF
D1, D10, D11, D12, D13, D14, D15, D16, D17, D18, D19, D2, D20, D21, D22, D23, D24, D3, D4, D5, D6, D7, D8, D9 | D_DO-35_SOD27_P7.62mm_Horizontal | 24 | 1N4148WS
J1 | PinSocket_1x03_P2.54mm_Horizontal | 1 | MOD Power
J2 | PinSocket_1x03_P2.54mm_Horizontal | 1 | MOD I/O
J3 | JST_EH_S3B-EH_1x03_P2.50mm_Horizontal | 1 | Dial_PowerConn
J4 | JST_PH_S8B-PH-K_1x08_P2.00mm_Horizontal | 1 | Dial_MagEncoderConn
J5 | JST_PH_S8B-PH-K_1x08_P2.00mm_Horizontal | 1 | Dial_MotorControlConn
LED1, LED10, LED11, LED12, LED13, LED14, LED15, LED16, LED17, LED18, LED19, LED2, LED20, LED21, LED3, LED4, LED5, LED6, LED7, LED8, LED9 | LED_MX_6028R | 21 | SK6812MINI-E
O1 | PinHeader_1x04_P2.54mm_Vertical | 1 | OLED_Display
R5, R6, R7, R8 | 0805 | 4 | 8.2k
RENC1, RENC2 | RotaryEncoder_Alps_EC11E-Switch_Vertical_H20mm | 2 | RotaryEncoder_Switch
ST_LA1, ST_LA2 | STAB_MX_2u | 2 | 2u
ST_LE1 | STAB_MX_3u | 1 | 3u
SW_LA1, SW_LA2 | SW_Hotswap_Kailh_MX_Plated_2.00u | 2 | SW_Push_45deg
SW_LB1, SW_LB2, SW_LB3, SW_LB4, SW_LC1, SW_LC2, SW_LC3, SW_LC4, SW_LD1, SW_LD2, SW_LD3, SW_LD4, SW_LE1, SW_RB1, SW_RB2, SW_RB3 | SW_Hotswap_Kailh_MX_Plated_1.00u | 16 | SW_Push_45deg
SW_LE2 | SW_Hotswap_Kailh_MX_Plated_3.00u | 1 | SW_Push_45deg
SW_MOD1 | SolderWire-0.127sqmm_1x02_P3.7mm_D0.48mm_OD1mm | 1 | Conn_01x02_Socket
SW_RA1, SW_RA2 | SW_Hotswap_Kailh_MX_Plated_1.50u | 2 | SW_Push_45deg
TP1 | TestPoint_THTPad_D1.5mm_Drill0.7mm | 1 | SDA
TP2 | TestPoint_THTPad_D1.5mm_Drill0.7mm | 1 | SCL
TP_3V1, TP_GND1, TP_VBUS1 | TestPoint_THTPad_D1.5mm_Drill0.7mm | 3 | VSYS test point
TP_KCOL1, TP_KCOL2, TP_KCOL3, TP_KCOL4, TP_KROW1, TP_KROW2, TP_KROW3, TP_KROW4, TP_KROW5, TP_KROW6, TP_LED1, TP_LED2 | TestPoint_THTPad_D1.5mm_Drill0.7mm | 12 | TestPoint
U2 | SOIC-16_3.9x9.9mm_P1.27mm | 1 | 74HC238
U3 | SOT-23-6_Handsoldering | 1 | SN74LVC1T45DBV

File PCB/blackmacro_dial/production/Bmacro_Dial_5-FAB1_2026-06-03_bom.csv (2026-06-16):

Designator | Footprint | Quantity | Value | LCSC Part #
C1, C2, C3, C5, C6 | 1206 | 5 | 0.1uf
C4 | 1210 | 1 | 22uF
J1 | JST_PH_S8B-PH-K_1x08_P2.00mm_Horizontal | 1 | MagEncoderConn
J2 | JST_PH_S8B-PH-K_1x08_P2.00mm_Horizontal | 1 | MotorControlConn | C20598766
J3 | JST_EH_S3B-EH_1x03_P2.50mm_Horizontal | 1 | MotorOutConn | C22382557
J4 | JST_EH_S3B-EH_1x03_P2.50mm_Horizontal | 1 | PowerConn | C22382557
TP1 | TestPoint_THTPad_D2.0mm_Drill1.0mm | 1 | MagEnc A
TP10 | TestPoint_THTPad_D2.0mm_Drill1.0mm | 1 | Motor Out W
TP11 | TestPoint_THTPad_D2.0mm_Drill1.0mm | 1 | 3V3
TP12 | TestPoint_THTPad_D2.0mm_Drill1.0mm | 1 | 5V
TP13 | TestPoint_THTPad_D2.0mm_Drill1.0mm | 1 | GND
TP2 | TestPoint_THTPad_D2.0mm_Drill1.0mm | 1 | MagEnc B
TP3 | TestPoint_THTPad_D2.0mm_Drill1.0mm | 1 | MagEnc Z
TP4 | TestPoint_THTPad_D2.0mm_Drill1.0mm | 1 | MagEnc Out
TP5 | TestPoint_THTPad_D2.0mm_Drill1.0mm | 1 | MagEnc Push
TP6 | TestPoint_THTPad_D2.0mm_Drill1.0mm | 1 | Motor Diagnostics
TP7 | TestPoint_THTPad_D2.0mm_Drill1.0mm | 1 | Motor VIO
TP8 | TestPoint_THTPad_D2.0mm_Drill1.0mm | 1 | Motor Out U
TP9 | TestPoint_THTPad_D2.0mm_Drill1.0mm | 1 | Motor Out V
U1 | SO-8_3.9x4.9mm_P1.27mm | 1 | MT6701CT
U2 | QFN-20-1EP_3x3mm_P0.4mm_EP1.65x1.65mm_ThermalVias_LargerViaHoles | 1 | TMC6300

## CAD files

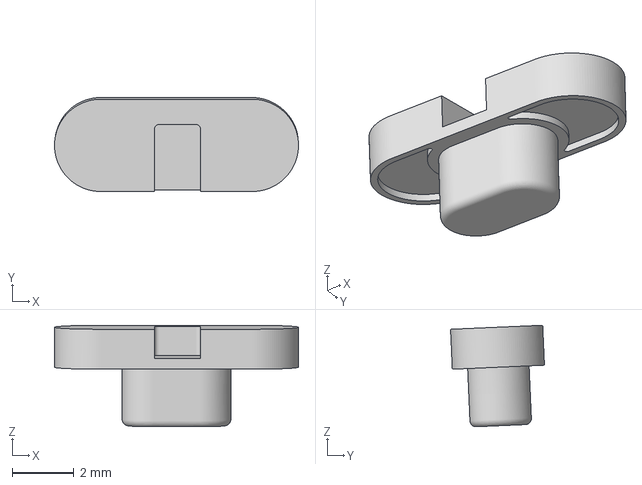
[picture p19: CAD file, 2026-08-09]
CAD/fab/Switch.3mf
7.93 x 3.05 x 3.30 mm

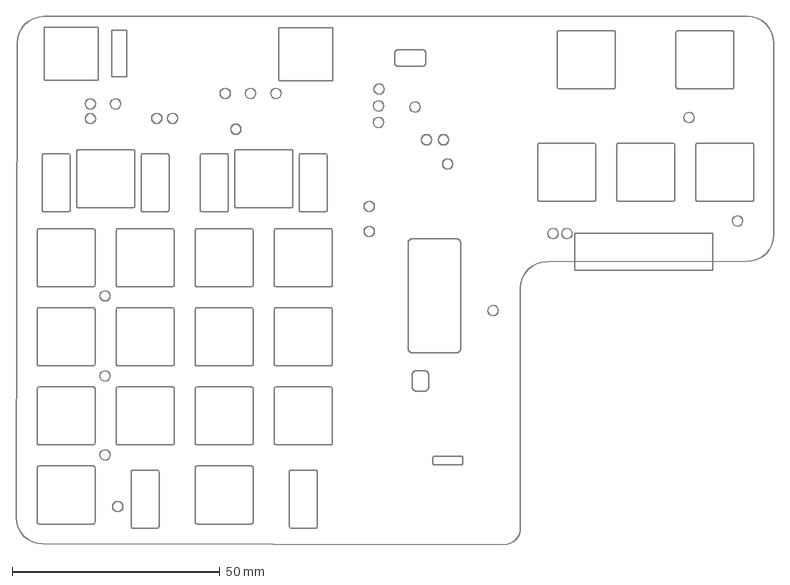
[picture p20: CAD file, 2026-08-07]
PCB/blackmacro_plate/plot/blackmacro_plate-Edge_Cuts.dxf
182.6 x 127.3 mm

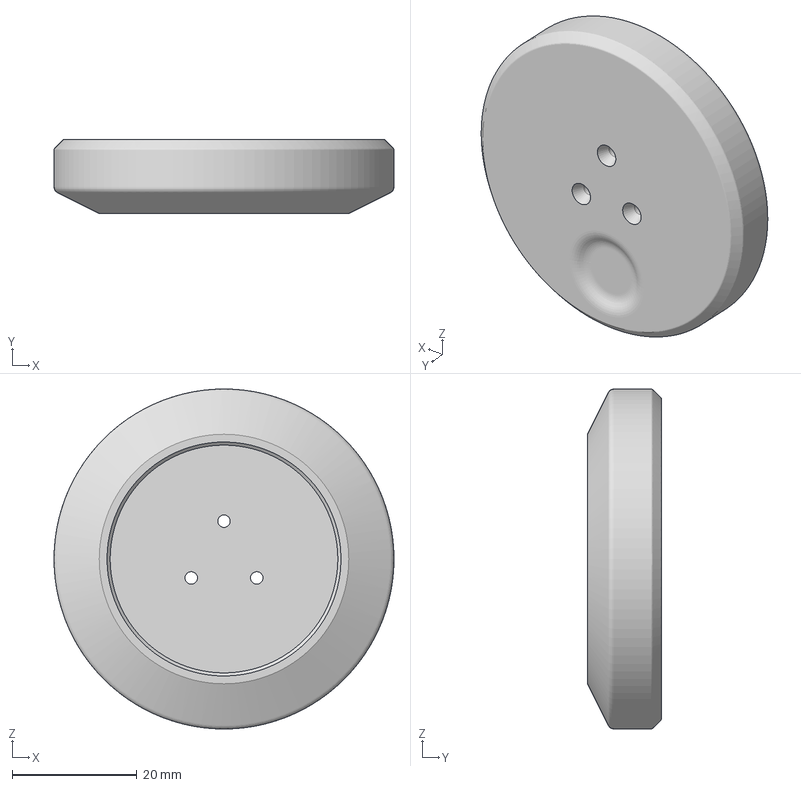
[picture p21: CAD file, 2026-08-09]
CAD/fab/Jog Wheel_divet.3mf
54.5 x 11.9 x 54.5 mm

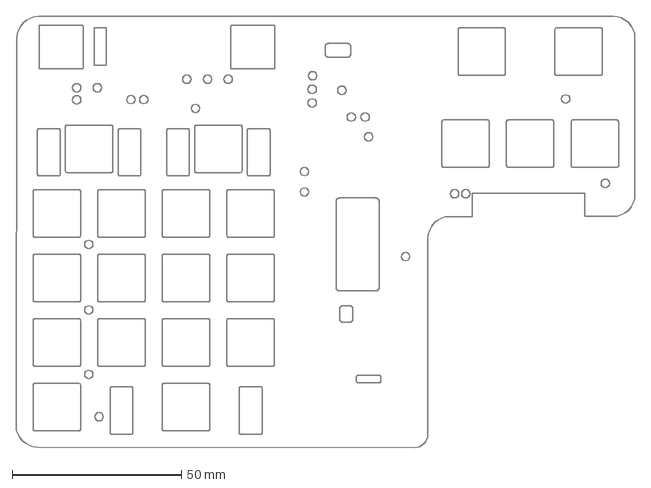
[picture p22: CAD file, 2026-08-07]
PCB/blackmacro_plate/plot/blackmacro_plate_fixed.dxf
182.6 x 127.3 mm

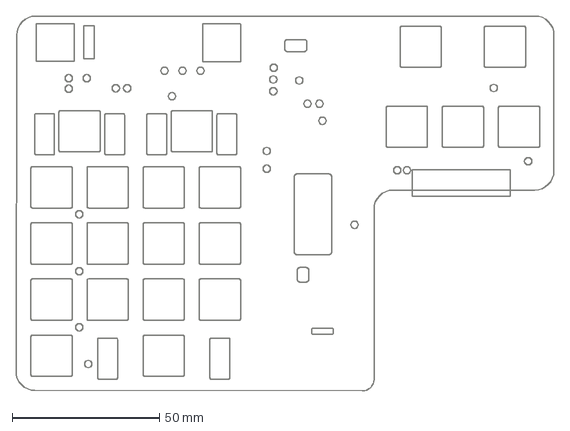
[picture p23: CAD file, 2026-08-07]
PCB/blackmacro_plate/plot/blackmacro_plate.dxf
182.6 x 127.3 mm

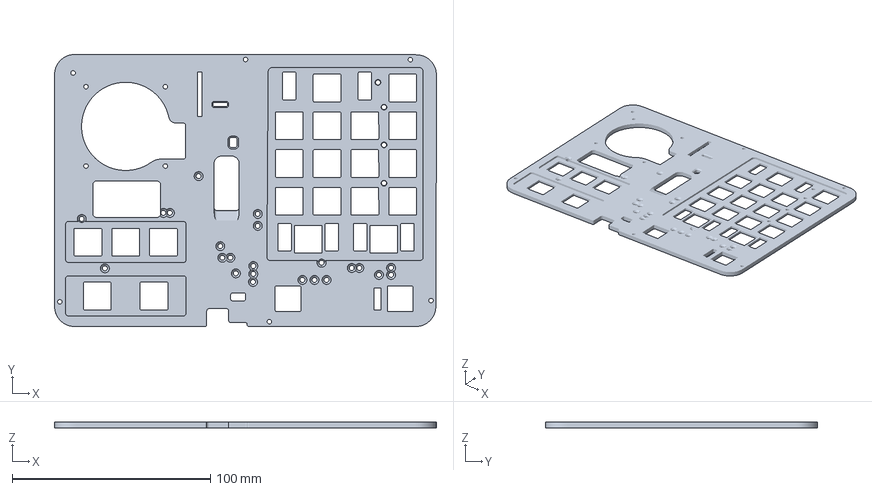
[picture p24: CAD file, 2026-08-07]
CAD/fab/Plate.3mf
192.6 x 137.3 x 3.00 mm

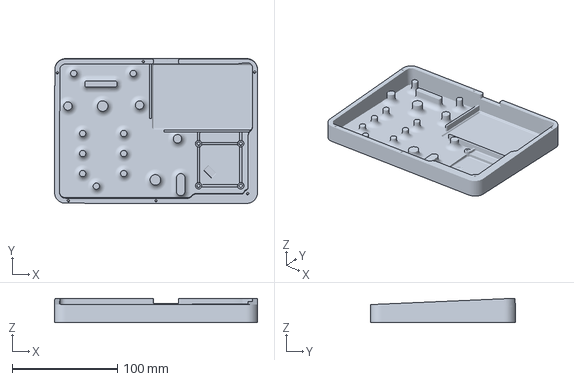
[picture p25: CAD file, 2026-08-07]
CAD/fab/Case Bottom.3mf
192.6 x 137.4 x 23.2 mm

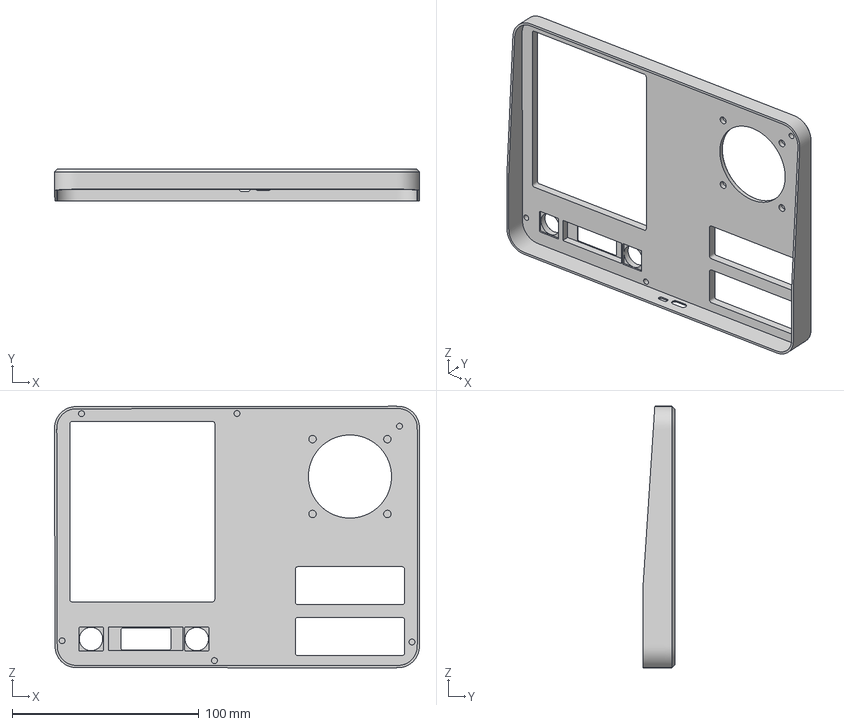
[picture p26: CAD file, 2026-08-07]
CAD/fab/Case Top.3mf
195.2 x 17.0 x 139.9 mm

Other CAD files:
CAD/Switch.step
PCB/blackmacro_base/3d/base_12-2-fab2.step
PCB/blackmacro_dial/3d/dial-v1-rev6-fab1.step
CAD/Case Top.step
PCB/blackmacro_base/3d/base-5-1-fab1.step
CAD/Case Bottom.step
CAD/fab/Jog Wheel.step
CAD/Jog Wheel.step
CAD/blackmacro_plate.step
CAD/Assembly V2.f3z
CAD/Case Bottom.f3d
CAD/Case Top.f3d
CAD/Jog Wheel.f3d
CAD/Switch.f3d
CAD/blackmacro_plate.f3d
CAD/fab/Jog Wheel.3mf
PCB/blackmacro_plate/plot/~blackmacro_plate_fixed.dxf

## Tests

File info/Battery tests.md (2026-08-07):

# Current
(Fullbright means 255,255,255 white)
- **No motor, no bluetooth, no screen, LED 100% rainbow**: 620mA
- **No motor, no bluetooth, no screen, LED 0%**: 56mA
- **No motor, no bluetooth, no screen, LED unknown% med brightness rainbow**: 138mA
  - **1 fullbright led**: 190mA
- **No motor, no bluetooth, no screen, LED 100% fullbright**: 1.58A

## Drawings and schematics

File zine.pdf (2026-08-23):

## A customizable macropad with a

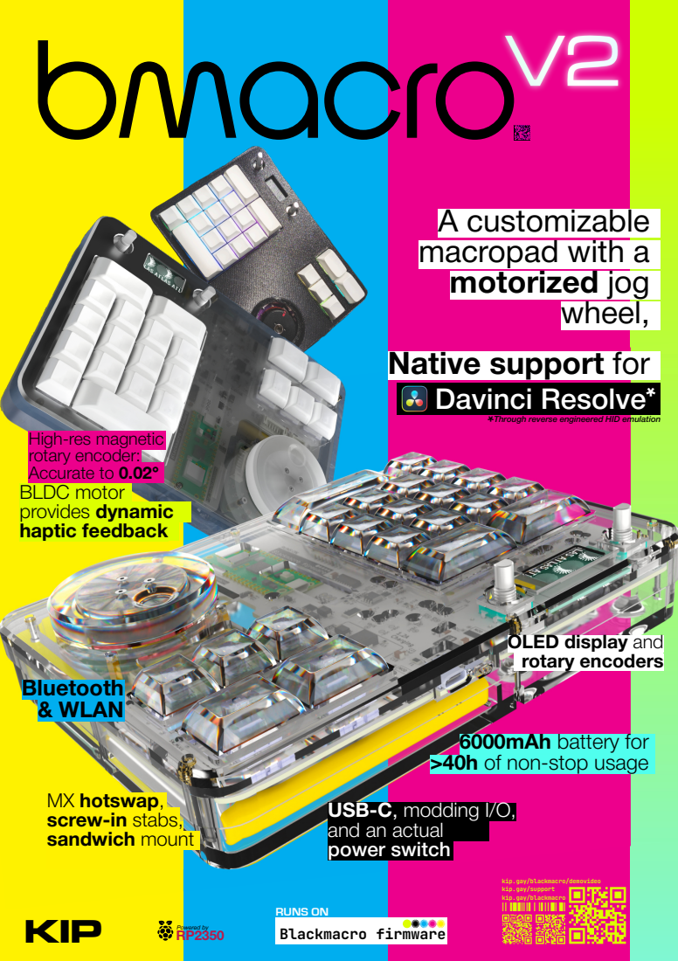
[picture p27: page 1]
RP2350 KIP; Powered by; Blackmacro firmware; RUNS ON; bmacro; Bluetooth & WLAN; motorized jog wheel,; BMacro

Native support for
Davinci Resolve

Through reverse engineered HID emulation

High-res magnetic
rotary encoder:
Accurate to 0.02°
BLDC motor
provides dynamic
haptic feedback

OLED display and
rotary encoders

6000mAh battery for
>40h of non-stop usage

MX hotswap,
screw-in stabs,
sandwich mount

USB-C, modding I/O,
and an actual
power switch

kip.gay/blackmacro/demovideo
kip.gay/support
kip.gay/blackmacro

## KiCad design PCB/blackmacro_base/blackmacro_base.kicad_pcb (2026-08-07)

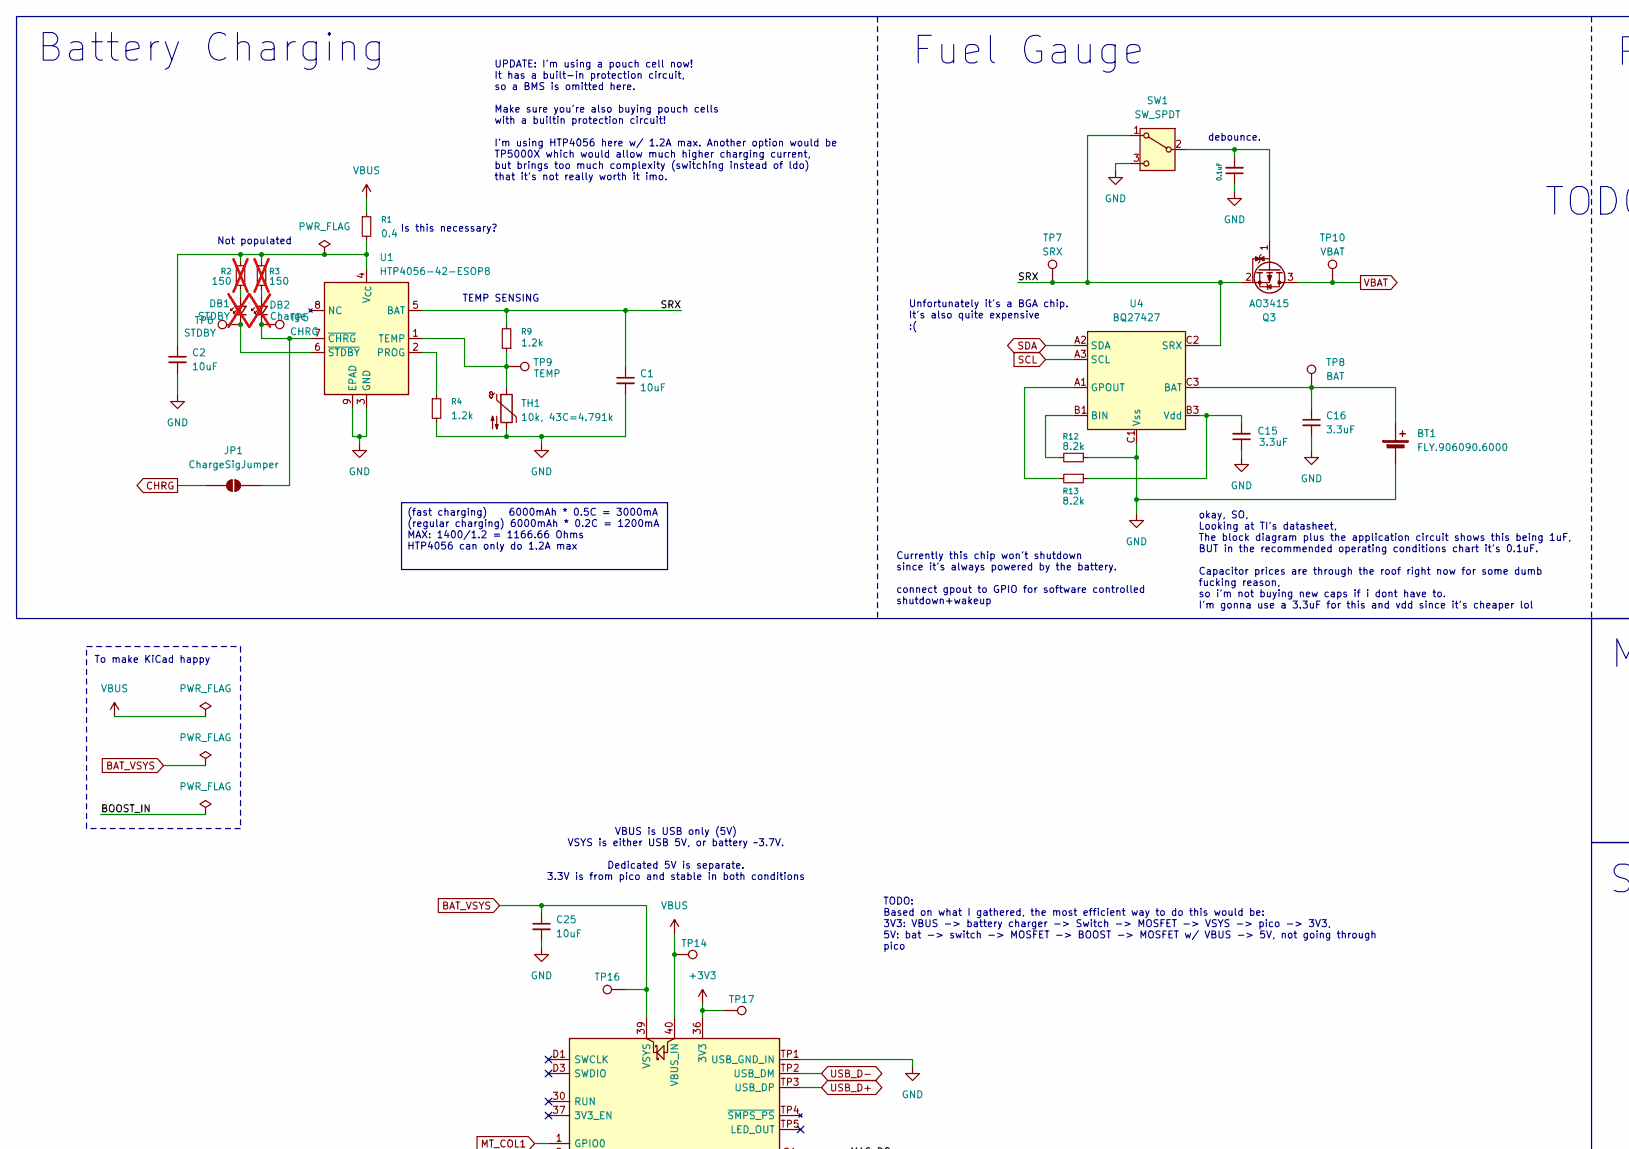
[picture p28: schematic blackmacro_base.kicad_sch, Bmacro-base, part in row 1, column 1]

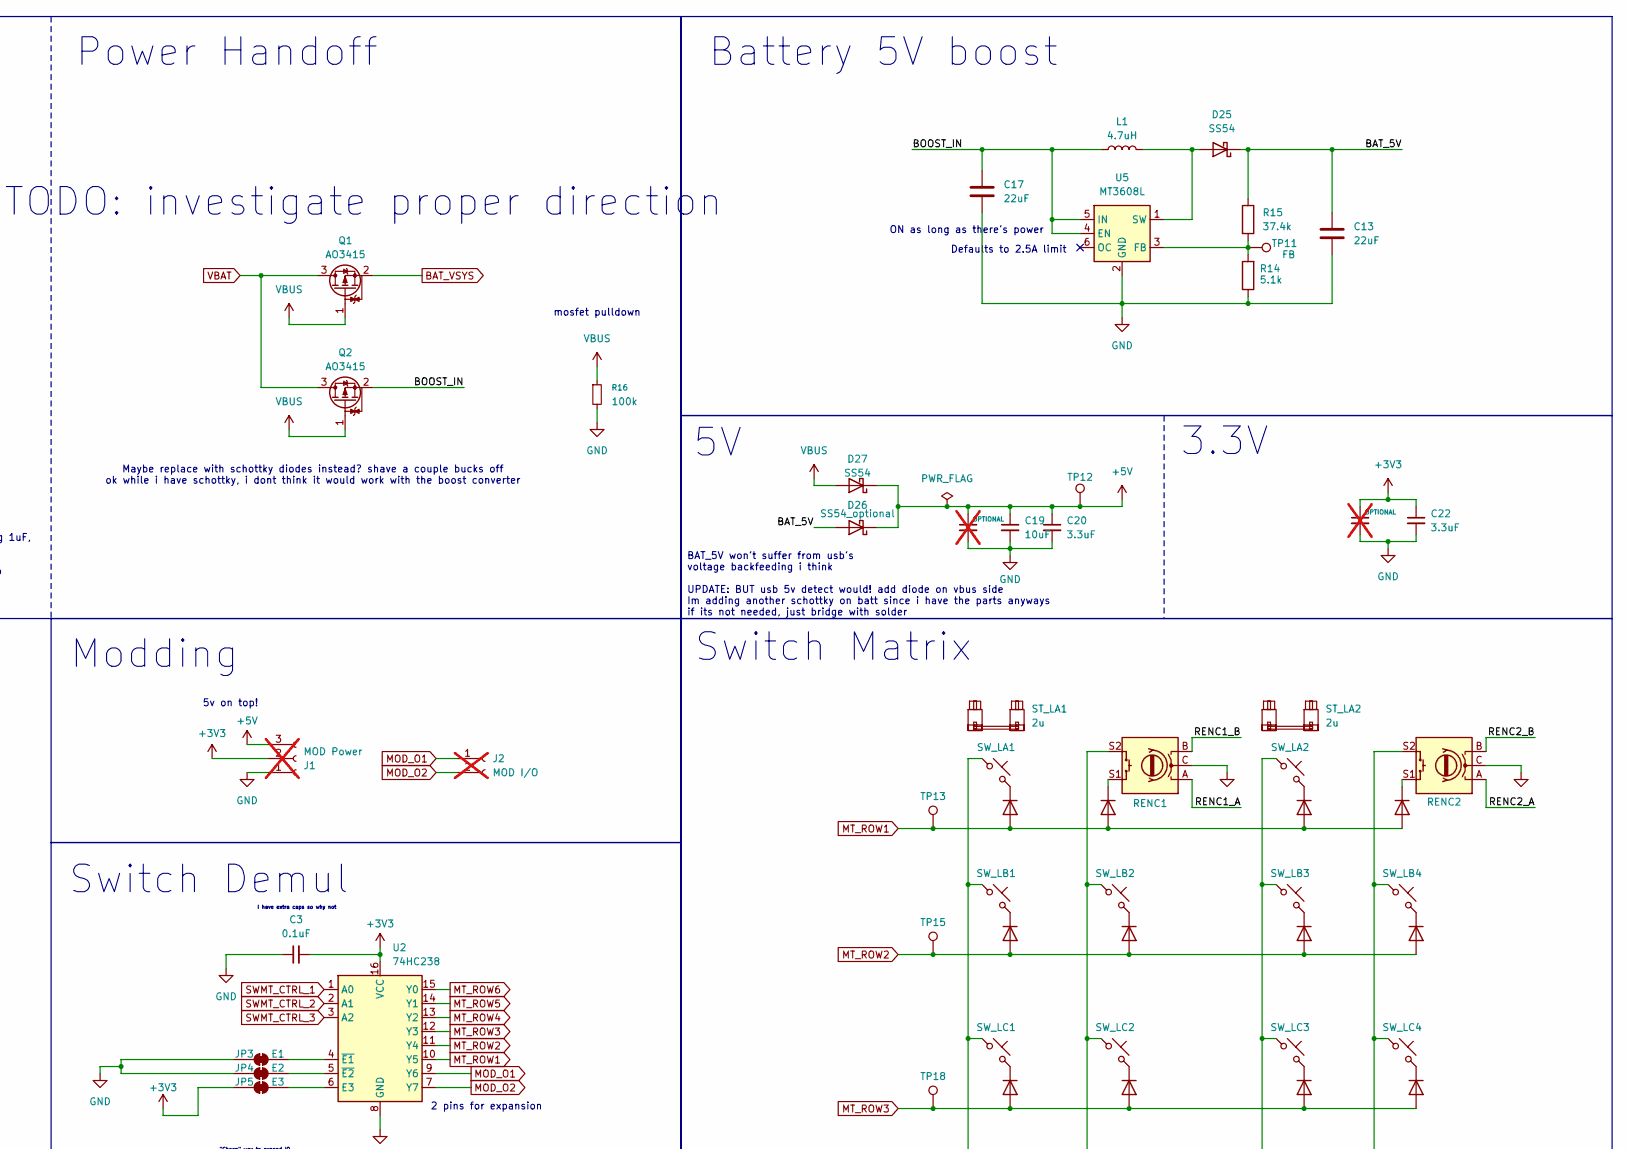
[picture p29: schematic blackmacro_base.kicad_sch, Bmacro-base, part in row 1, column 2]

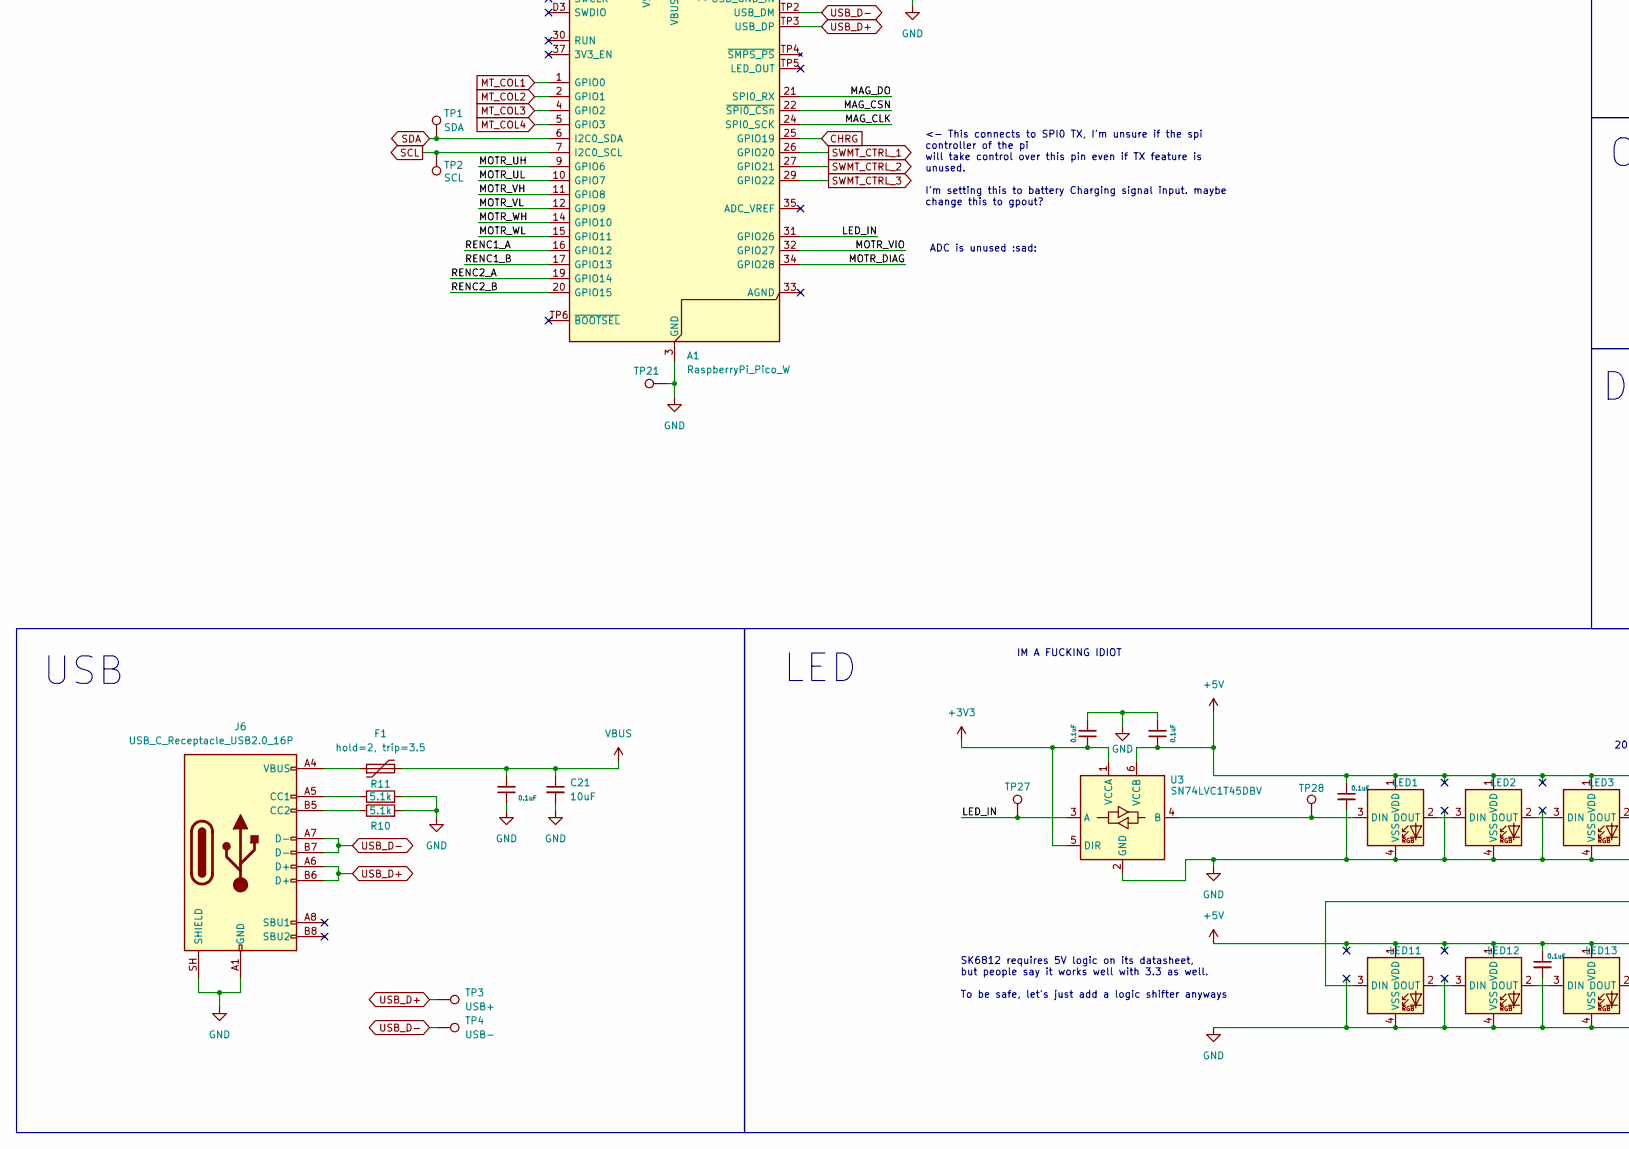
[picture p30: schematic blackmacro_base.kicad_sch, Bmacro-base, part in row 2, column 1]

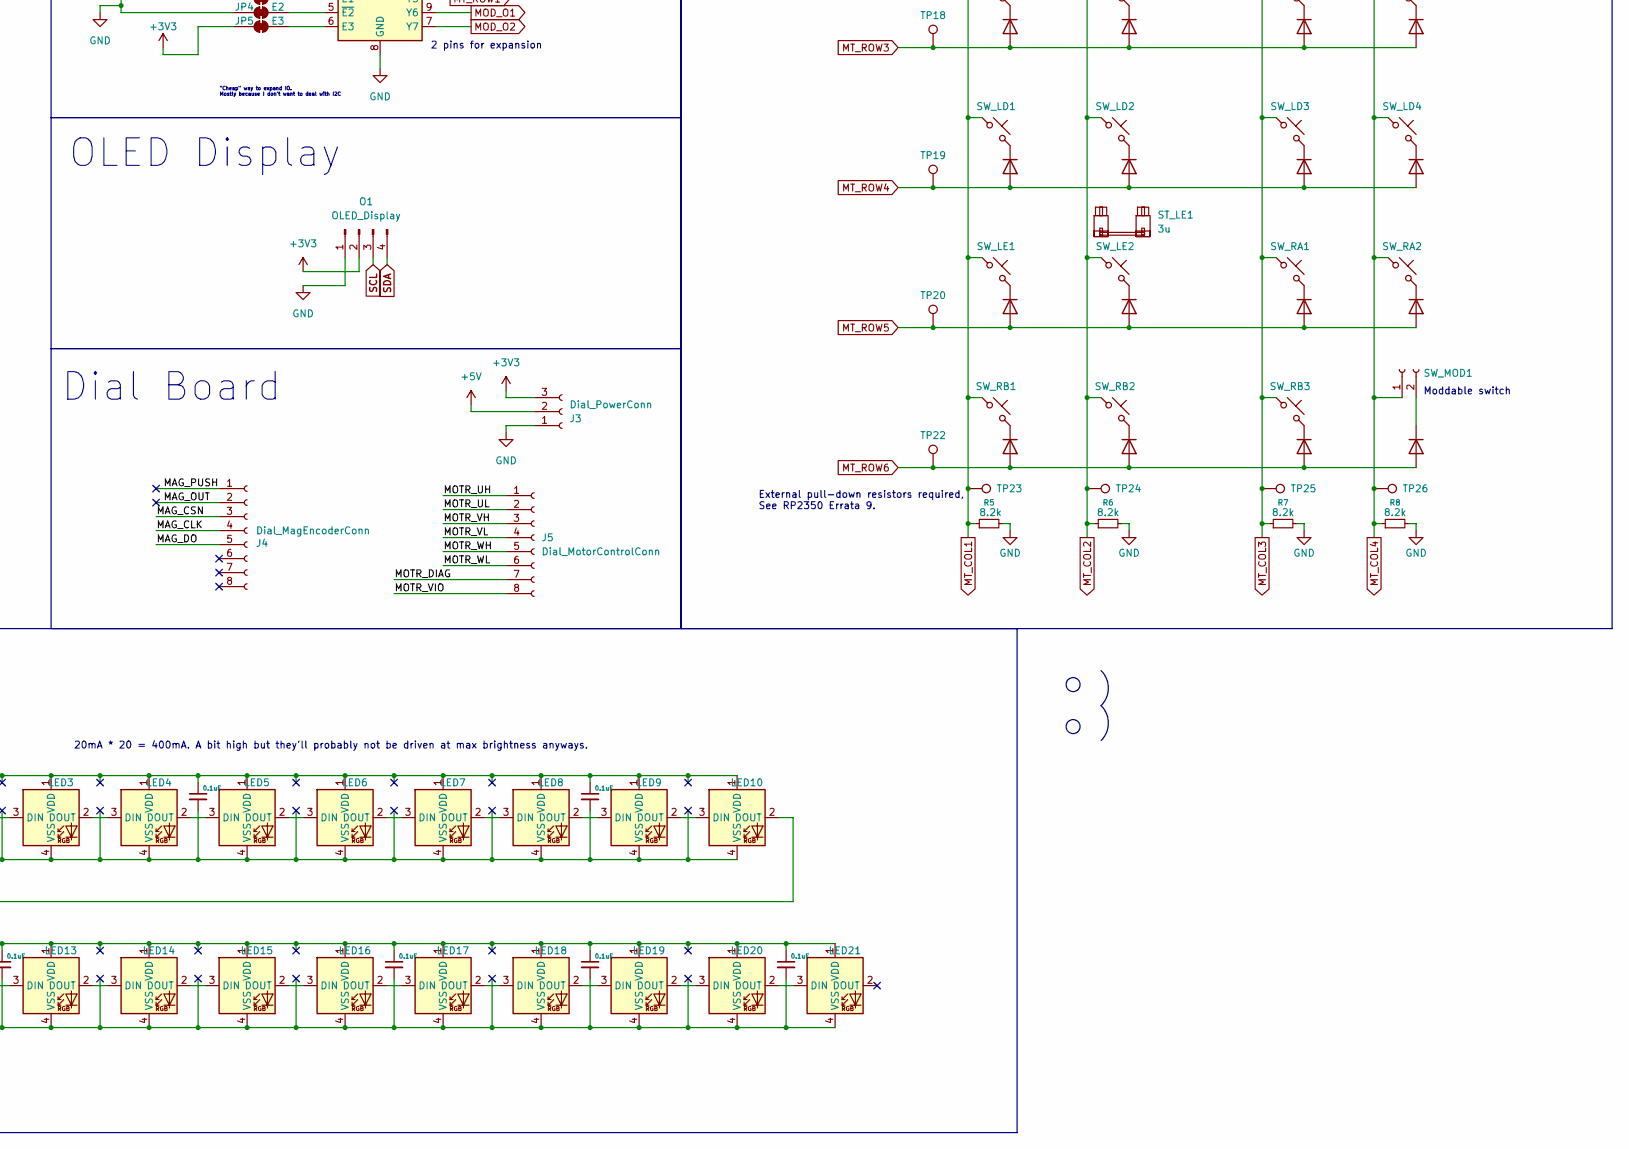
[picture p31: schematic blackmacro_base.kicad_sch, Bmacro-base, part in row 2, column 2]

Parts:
A1: RaspberryPi_Pico_W; RaspberryPi_Pico_W_SMD_THTdebug
BT1: FLY.906090.6000; JST_EH_S3B-EH_1x03_P2.50mm_Horizontal
C1, C2, C19, C21, C25: 10uF; C_0603_1608Metric_Pad1.08x0.95mm_HandSolder
C3, C4, C5, C6, C7, C8, C9, C10, C11, C12, C14, C18: 0.1uF; C_1206_3216Metric_Pad1.33x1.80mm_HandSolder
C13, C17: 22uF; C_0603_1608Metric_Pad1.08x0.95mm_HandSolder
C15, C16, C20, C22: 3.3uF; C_0603_1608Metric_Pad1.08x0.95mm_HandSolder
C23, C24: OPTIONAL; C_1206_3216Metric_Pad1.33x1.80mm_HandSolder; not fitted
D1, D2, D3, D4, D5, D6, D7, D8, D9, D10, D11, D12, D13, D14, D15, D16, D17, D18, D19, D20, D21, D22, D23, D24: 1N4148WS; D_DO-35_SOD27_P7.62mm_Horizontal
D25, D27: SS54; D_SMA_Handsoldering
D26: SS54_optional; D_SMA_Handsoldering
DB1: STDBY; LED_0603_1608Metric_Pad1.05x0.95mm_HandSolder; not fitted
DB2: Charge; LED_0603_1608Metric_Pad1.05x0.95mm_HandSolder; not fitted
F1: hold=2, trip=3.5; Fuse_1206_3216Metric_Pad1.42x1.75mm_HandSolder
J1: MOD Power; PinSocket_1x03_P2.54mm_Horizontal; not fitted
J2: MOD I/O; PinSocket_1x02_P2.54mm_Horizontal; not fitted
J3: Dial_PowerConn; JST_EH_S3B-EH_1x03_P2.50mm_Horizontal
J4: Dial_MagEncoderConn; JST_PH_S8B-PH-K_1x08_P2.00mm_Horizontal
J5: Dial_MotorControlConn; JST_PH_S8B-PH-K_1x08_P2.00mm_Horizontal
J6: USB_C_Receptacle_USB2.0_16P; USB_C_Receptacle_HCTL_HC-TYPE-C-16P-01A
JP1: ChargeSigJumper; SolderJumper-2_P1.3mm_Open_TrianglePad1.0x1.5mm
JP3: E1; SolderJumper-2_P1.3mm_Bridged_RoundedPad1.0x1.5mm
JP4: E2; SolderJumper-2_P1.3mm_Bridged_RoundedPad1.0x1.5mm
JP5: E3; SolderJumper-2_P1.3mm_Bridged_RoundedPad1.0x1.5mm
L1: 4.7uH; L_Changjiang_FXL0630
LED1, LED2, LED3, LED4, LED5, LED6, LED7, LED8, LED9, LED10, LED11, LED12, LED13, LED14, LED15, LED16, LED17, LED18, LED19, LED20, LED21: SK6812MINI-E; LED_MX_6028R
O1: OLED_Display; PinHeader_1x04_P2.54mm_Vertical
Q1, Q2, Q3: AO3415; SOT-23_Handsoldering
R1: 0.4; R_2512_6332Metric_Pad1.40x3.35mm_HandSolder
R2, R3: 150; R_0603_1608Metric_Pad0.98x0.95mm_HandSolder; not fitted
R4, R9: 1.2k; R_0805_2012Metric_Pad1.20x1.40mm_HandSolder
R5, R6, R7, R8, R12, R13: 8.2k; R_0805_2012Metric_Pad1.20x1.40mm_HandSolder
R10, R11, R14: 5.1k; R_0603_1608Metric_Pad0.98x0.95mm_HandSolder
R15: 37.4k; R_0603_1608Metric_Pad0.98x0.95mm_HandSolder
R16: 100k; R_0603_1608Metric_Pad0.98x0.95mm_HandSolder
RENC1, RENC2: RotaryEncoder_Switch; RotaryEncoder_Alps_EC11E-Switch_Vertical_H20mm
ST_LA1, ST_LA2: 2u; STAB_MX_2u
ST_LE1: 3u; STAB_MX_3u
SW1: SW_SPDT; SW_SPDT_Shouhan_MSK12C02
SW_LA1, SW_LA2: SW_Push_45deg; SW_Hotswap_Kailh_MX_Plated_2.00u
SW_LB1, SW_LB2, SW_LB3, SW_LB4: SW_Push_45deg; SW_Hotswap_Kailh_MX_Plated_1.00u
SW_LC1, SW_LC2, SW_LC3, SW_LC4: SW_Push_45deg; SW_Hotswap_Kailh_MX_Plated_1.00u
SW_LD1, SW_LD2, SW_LD3, SW_LD4: SW_Push_45deg; SW_Hotswap_Kailh_MX_Plated_1.00u
SW_LE1: SW_Push_45deg; SW_Hotswap_Kailh_MX_Plated_1.00u
SW_LE2: SW_Push_45deg; SW_Hotswap_Kailh_MX_Plated_3.00u
SW_MOD1: Conn_01x02_Socket; SolderWire-0.127sqmm_1x02_P3.7mm_D0.48mm_OD1mm
SW_RA1, SW_RA2: SW_Push_45deg; SW_Hotswap_Kailh_MX_Plated_1.50u
SW_RB1, SW_RB2, SW_RB3: SW_Push_45deg; SW_Hotswap_Kailh_MX_Plated_1.00u
TH1: 10k, 43C=4.791k; SolderWire-0.127sqmm_1x02_P3.7mm_D0.48mm_OD1mm_Relief
TP1: SDA; TestPoint_THTPad_D1.5mm_Drill0.7mm
TP2: SCL; TestPoint_THTPad_D1.5mm_Drill0.7mm
TP3: USB+; TestPoint_Pad_D1.5mm
TP4: USB-; TestPoint_Pad_D1.5mm
TP5: CHRG; TestPoint_Pad_D1.5mm
TP6: STDBY; TestPoint_Pad_D1.5mm
TP7: SRX; TestPoint_THTPad_D1.5mm_Drill0.7mm
TP8: BAT; TestPoint_THTPad_D1.5mm_Drill0.7mm
TP9: TEMP; TestPoint_Pad_D1.5mm
TP10: VBAT; TestPoint_THTPad_D1.5mm_Drill0.7mm
TP11: FB; TestPoint_Pad_D1.0mm
TP12: 5V; TestPoint_THTPad_D1.5mm_Drill0.7mm
TP13: KROW1; TestPoint_Pad_D1.0mm
TP14: VBUS; TestPoint_THTPad_D1.5mm_Drill0.7mm
TP15: KROW2; TestPoint_Pad_D1.0mm
TP16: VSYS; TestPoint_Pad_D1.5mm
TP17: 3V3; TestPoint_THTPad_D1.5mm_Drill0.7mm
TP18: KROW3; TestPoint_Pad_D1.0mm
TP19: KROW4; TestPoint_Pad_D1.0mm
TP20: KROW5; TestPoint_Pad_D1.0mm
TP21: GND; TestPoint_THTPad_D1.5mm_Drill0.7mm
TP22: KROW6; TestPoint_Pad_D1.0mm
TP23: KCOL1; TestPoint_Pad_D1.0mm
TP24: KCOL2; TestPoint_Pad_D1.0mm
TP25: KCOL3; TestPoint_Pad_D1.0mm
TP26: KCOL4; TestPoint_Pad_D1.0mm
TP27: LED1; TestPoint_Pad_D1.5mm
TP28: LED2; TestPoint_Pad_D1.5mm
U1: HTP4056-42-ESOP8; SOIC-8-1EP_3.9x4.9mm_P1.27mm_EP2.41x3.3mm_ThermalVias
U2: 74HC238; SOIC-16_3.9x9.9mm_P1.27mm
U3: SN74LVC1T45DBV; SOT-23-6_Handsoldering
U4: BQ27427; Texas_DSBGA-9_1.62x1.58mm_Layout3x3_P0.5mm
U5: MT3608L; SOT-23-6_Handsoldering

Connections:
+3V3: A1.36 (3V3), C3.2, C5.1, C22.1, C23.1, J1.2, J3.3, JP5.1 (A), O1.2, TP17.1 (1_1), U2.16 (VCC), U3.1 (VCCA), U3.5 (DIR)
+5V: C4.1, C6.1, C7.1, C8.1, C9.1, C10.1, C11.1, C12.1, C19.1, C20.1, C24.1, D26.1 (K), D27.1 (K), J1.3, J3.2, LED1.1 (VDD), LED2.1 (VDD), LED3.1 (VDD), LED4.1 (VDD), LED5.1 (VDD), LED6.1 (VDD), LED7.1 (VDD), LED8.1 (VDD), LED9.1 (VDD), LED10.1 (VDD), LED11.1 (VDD), LED12.1 (VDD), LED13.1 (VDD), LED14.1 (VDD), LED15.1 (VDD), LED16.1 (VDD), LED17.1 (VDD), LED18.1 (VDD), LED19.1 (VDD), LED20.1 (VDD), LED21.1 (VDD), TP12.1 (1_1), U3.6 (VCCB)
/BAT_5V: C13.1, D25.1 (K), D26.2 (A), R15.1
/BOOST_IN: C17.1, L1.1, Q2.2 (S), U5.4 (EN), U5.5 (IN)
/LED_IN: A1.31 (GPIO26), TP27.1 (1_1), U3.3 (A)
/MAG_CLK: A1.24 (SPI0_SCK), J4.4
/MAG_CSN: A1.22 (~SPI0_CSn), J4.3
/MAG_DO: A1.21 (SPI0_RX), J4.5
/MAG_OUT: J4.2
/MAG_PUSH: J4.1
/MOTR_DIAG: A1.34 (GPIO28), J5.7
/MOTR_UH: A1.9 (GPIO6), J5.1
/MOTR_UL: A1.10 (GPIO7), J5.2
/MOTR_VH: A1.11 (GPIO8), J5.3
/MOTR_VIO: A1.32 (GPIO27), J5.8
/MOTR_VL: A1.12 (GPIO9), J5.4
/MOTR_WH: A1.14 (GPIO10), J5.5
/MOTR_WL: A1.15 (GPIO11), J5.6
/RENC1_A: A1.16 (GPIO12), RENC1.A
/RENC1_B: A1.17 (GPIO13), RENC1.B
/RENC2_A: A1.19 (GPIO14), RENC2.A
/RENC2_B: A1.20 (GPIO15), RENC2.B
/SRX: C1.1, Q3.2 (S), R9.2, SW1.1 (A), TP7.1 (1_1), U1.5 (BAT), U4.C2 (SRX)
BAT_VSYS: A1.39 (VSYS), C25.1, Q1.2 (S), TP16.1 (1_1)
CHRG: A1.25 (GPIO19), JP1.2 (B)
GND: A1.3 (GND), A1.8 (GND), A1.13 (GND), A1.18 (GND), A1.23 (GND), A1.28 (GND), A1.38 (GND), A1.D2 (GND), A1.TP1 (USB_GND_IN), BT1.2 (-), C1.2, C2.2, C3.1, C4.2, C5.2, C6.2, C7.2, C8.2, C9.2, C10.2, C11.2, C12.2, C13.2, C14.1, C15.1, C16.2, C17.2, C18.1, C19.2, C20.2, C21.2, C22.2, C23.2, C24.2, C25.2, J1.1, J3.1, J6.A1 (GND), J6.A12 (GND), J6.B1 (GND), J6.B12 (GND), J6.SH (SHIELD), JP3.1 (A), JP4.1 (A), LED1.4 (VSS), LED2.4 (VSS), LED3.4 (VSS), LED4.4 (VSS), LED5.4 (VSS), LED6.4 (VSS), LED7.4 (VSS), LED8.4 (VSS), LED9.4 (VSS), LED10.4 (VSS), LED11.4 (VSS), LED12.4 (VSS), LED13.4 (VSS), LED14.4 (VSS), LED15.4 (VSS), LED16.4 (VSS), LED17.4 (VSS), LED18.4 (VSS), LED19.4 (VSS), LED20.4 (VSS), LED21.4 (VSS), O1.1, R4.2, R5.2, R6.2, R7.2, R8.2, R10.2, R11.2, R12.1, R14.1, R16.2, RENC1.C, RENC2.C, SW1.3 (C), TH1.2, TP21.1 (1_1), U1.3 (GND), U1.9 (EPAD), U2.8 (GND), U3.2 (GND), U4.B2 (Vss), U4.C1 (Vss), U5.2 (GND)
MOD_O1: J2.1, U2.9 (Y6)
MOD_O2: J2.2, U2.7 (Y7)
MT_COL1: A1.1 (GPIO0), R5.1, SW_LA1.1, SW_LB1.1, SW_LC1.1, SW_LD1.1, SW_LE1.1, SW_RB1.1, TP23.1 (1_1)
MT_COL2: A1.2 (GPIO1), R6.1, RENC1.S2, SW_LB2.1, SW_LC2.1, SW_LD2.1, SW_LE2.1, SW_RB2.1, TP24.1 (1_1)
MT_COL3: A1.4 (GPIO2), R7.1, SW_LA2.1, SW_LB3.1, SW_LC3.1, SW_LD3.1, SW_RA1.1, SW_RB3.1, TP25.1 (1_1)
MT_COL4: A1.5 (GPIO3), R8.1, RENC2.S2, SW_LB4.1, SW_LC4.1, SW_LD4.1, SW_MOD1.1, SW_RA2.1, TP26.1 (1_1)
MT_ROW1: D1.2 (A), D2.2 (A), D3.2 (A), D4.2 (A), TP13.1 (1_1), U2.10 (Y5)
MT_ROW2: D5.2 (A), D6.2 (A), D7.2 (A), D8.2 (A), TP15.1 (1_1), U2.11 (Y4)
MT_ROW3: D9.2 (A), D10.2 (A), D11.2 (A), D12.2 (A), TP18.1 (1_1), U2.12 (Y3)
MT_ROW4: D13.2 (A), D14.2 (A), D15.2 (A), D16.2 (A), TP19.1 (1_1), U2.13 (Y2)
MT_ROW5: D17.2 (A), D18.2 (A), D19.2 (A), D20.2 (A), TP20.1 (1_1), U2.14 (Y1)
MT_ROW6: D21.2 (A), D22.2 (A), D23.2 (A), D24.2 (A), TP22.1 (1_1), U2.15 (Y0)
unnamed: BT1.1 (+), C16.1, TP8.1 (1_1), U4.C3 (BAT)
unnamed: D1.1 (K), SW_LA1.2
unnamed: D2.1 (K), SW_LA2.2
unnamed: D3.1 (K), RENC1.S1
unnamed: D4.1 (K), RENC2.S1
unnamed: D5.1 (K), SW_LB1.2
unnamed: D6.1 (K), SW_LB2.2
unnamed: D7.1 (K), SW_LB3.2
unnamed: D8.1 (K), SW_LB4.2
unnamed: D9.1 (K), SW_LC1.2
unnamed: D10.1 (K), SW_LC2.2
unnamed: D11.1 (K), SW_LC3.2
unnamed: D12.1 (K), SW_LC4.2
unnamed: D13.1 (K), SW_LD1.2
unnamed: D14.1 (K), SW_LD2.2
unnamed: D15.1 (K), SW_LD3.2
unnamed: D16.1 (K), SW_LD4.2
unnamed: D17.1 (K), SW_LE1.2
unnamed: D18.1 (K), SW_LE2.2
unnamed: D19.1 (K), SW_RA1.2
unnamed: D20.1 (K), SW_RA2.2
unnamed: D21.1 (K), SW_RB1.2
unnamed: D22.1 (K), SW_RB2.2
unnamed: D23.1 (K), SW_RB3.2
unnamed: D24.1 (K), SW_MOD1.2
unnamed: D25.2 (A), L1.2, U5.1 (SW)
unnamed: DB1.2 (A), R2.2
unnamed: DB1.1 (K), TP6.1 (1_1), U1.6 (~STDBY)
unnamed: DB2.2 (A), R3.2
unnamed: DB2.1 (K), JP1.1 (A), TP5.1 (1_1), U1.7 (~CHRG)
unnamed: F1.1, J6.A4 (VBUS), J6.A9 (VBUS), J6.B4 (VBUS), J6.B9 (VBUS)
unnamed: J6.A5 (CC1), R11.1
unnamed: J6.B5 (CC2), R10.1
unnamed: JP3.2 (B), U2.4 (~E1)
unnamed: JP4.2 (B), U2.5 (~E2)
unnamed: JP5.2 (B), U2.6 (E3)
unnamed: LED1.3 (DIN), TP28.1 (1_1), U3.4 (B)
unnamed: LED1.2 (DOUT), LED2.3 (DIN)
unnamed: LED2.2 (DOUT), LED3.3 (DIN)
unnamed: LED3.2 (DOUT), LED4.3 (DIN)
unnamed: LED4.2 (DOUT), LED5.3 (DIN)
unnamed: LED5.2 (DOUT), LED6.3 (DIN)
unnamed: LED6.2 (DOUT), LED7.3 (DIN)
unnamed: LED7.2 (DOUT), LED8.3 (DIN)
unnamed: LED8.2 (DOUT), LED9.3 (DIN)
unnamed: LED9.2 (DOUT), LED10.3 (DIN)
unnamed: LED10.2 (DOUT), LED11.3 (DIN)
unnamed: LED11.2 (DOUT), LED12.3 (DIN)
unnamed: LED12.2 (DOUT), LED13.3 (DIN)
unnamed: LED13.2 (DOUT), LED14.3 (DIN)
unnamed: LED14.2 (DOUT), LED15.3 (DIN)
unnamed: LED15.2 (DOUT), LED16.3 (DIN)
unnamed: LED16.2 (DOUT), LED17.3 (DIN)
unnamed: LED17.2 (DOUT), LED18.3 (DIN)
unnamed: LED18.2 (DOUT), LED19.3 (DIN)
unnamed: LED19.2 (DOUT), LED20.3 (DIN)
unnamed: LED20.2 (DOUT), LED21.3 (DIN)
unnamed: C14.2, Q3.1 (G), SW1.2 (B)
unnamed: R4.1, U1.2 (PROG)
unnamed: R9.1, TH1.1, TP9.1 (1_1), U1.1 (TEMP)
unnamed: C2.1, R1.2, R2.1, R3.1, U1.4 (V_{CC})
unnamed: R12.2, U4.B1 (BIN)
unnamed: R13.2, U4.A1 (GPOUT)
unnamed: C15.2, R13.1, U4.B3 (Vdd)
unnamed: R14.2, R15.2, TP11.1 (1_1), U5.3 (FB)
SCL: A1.7 (I2C0_SCL), O1.3, TP2.1 (1_1), U4.A3 (SCL)
SDA: A1.6 (I2C0_SDA), O1.4, TP1.1 (1_1), U4.A2 (SDA)
SWMT_CTRL_1: A1.26 (GPIO20), U2.1 (A0)
SWMT_CTRL_2: A1.27 (GPIO21), U2.2 (A1)
SWMT_CTRL_3: A1.29 (GPIO22), U2.3 (A2)
USB_D+: A1.TP3 (USB_DP), J6.A6 (D+), J6.B6 (D+), TP3.1 (1_1)
USB_D-: A1.TP2 (USB_DM), J6.A7 (D-), J6.B7 (D-), TP4.1 (1_1)
VBAT: Q1.3 (D), Q2.3 (D), Q3.3 (D), TP10.1 (1_1)
VBUS: A1.40 (VBUS_IN), C18.2, C21.1, D27.2 (A), F1.2, Q1.1 (G), Q2.1 (G), R1.1, R16.1, TP14.1 (1_1)

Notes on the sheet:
Dial Board
SK6812 requires 5V logic on its datasheet, but people say it works well with 3.3 as well. To be safe, let's just add a logic shifter anyways
3.3V
Battery Charging
Fuel Gauge
TEMP SENSING
5v on top!
mosfet pulldown
Battery 5V boost
TODO: investigate proper direction
Defaults to 2.5A limit
"Cheap" way to expand IO. Mostly because I don't want to deal with I2C
VBUS is USB only (5V) VSYS is either USB 5V, or battery ~3.7V. Dedicated 5V is separate. 3.3V is from pico and stable in both conditions
Currently this chip won't shutdown since it's always powered by the battery. connect gpout to GPIO for software controlled shutdown+wakeup
Power Handoff
BAT_5V won't suffer from usb's voltage backfeeding i think UPDATE: BUT usb 5v detect would! add diode on vbus side Im adding another schottky on batt since i have the parts anyways if its not needed, just bridge with solder
USB
Switch Matrix
OLED Display
To make KiCad happy
2 pins for expansion
Switch Demul
debounce.
External pull-down resistors required, See RP2350 Errata 9.
ON as long as there's power
Is this necessary?
Not populated
LED
okay, SO, Looking at TI's datasheet, The block diagram plus the application circuit shows this being 1uF, BUT in the recommended operating conditions chart it's 0.1uF. Capacitor prices are through the roof right now for some dumb fucking reason, so i'm not buying new caps if i dont have to. I'm gon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
IM A FUCKING IDIOT
Maybe replace with schottky diodes instead? shave a couple bucks off ok while i have schottky, i dont think it would work with the boost converter
I have extra caps so why not
Unfortunately it's a BGA chip. It's also quite expensive :(
UPDATE: I'm using a pouch cell now! It has a built-in protection circuit, so a BMS is omitted here. Make sure you're also buying pouch cells with a builtin protection circuit! I'm using HTP4056 here w/ 1.2A max. Another option would be TP5000X which would allow much higher charging current, but bri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
Modding
20mA * 20 = 400mA. A bit high but they'll probably not be driven at max brightness anyways.
Moddable switch
ADC is unused :sad:
TODO: Based on what I gathered, the most efficient way to do this would be: 3V3: VBUS -> battery charger -> Switch -> MOSFET -> VSYS -> pico -> 3V3, 5V: bat -> switch -> MOSFET -> BOOST -> MOSFET w/ VBUS -> 5V, not going through pico
(fast charging) 6000mAh * 0.5C = 3000mA (regular charging) 6000mAh * 0.2C = 1200mA MAX: 1400/1.2 = 1166.66 Ohms HTP4056 can only do 1.2A max

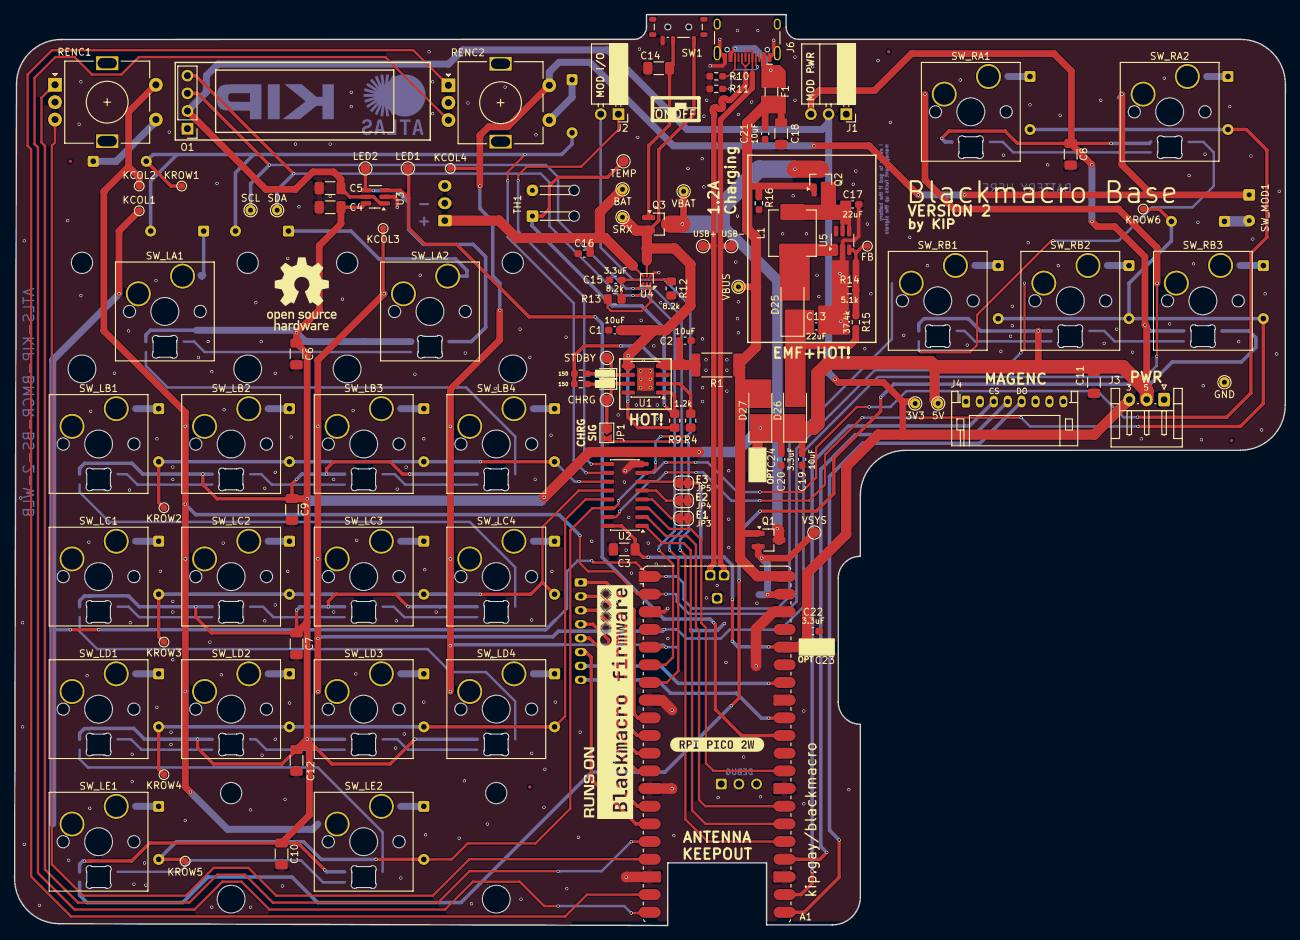
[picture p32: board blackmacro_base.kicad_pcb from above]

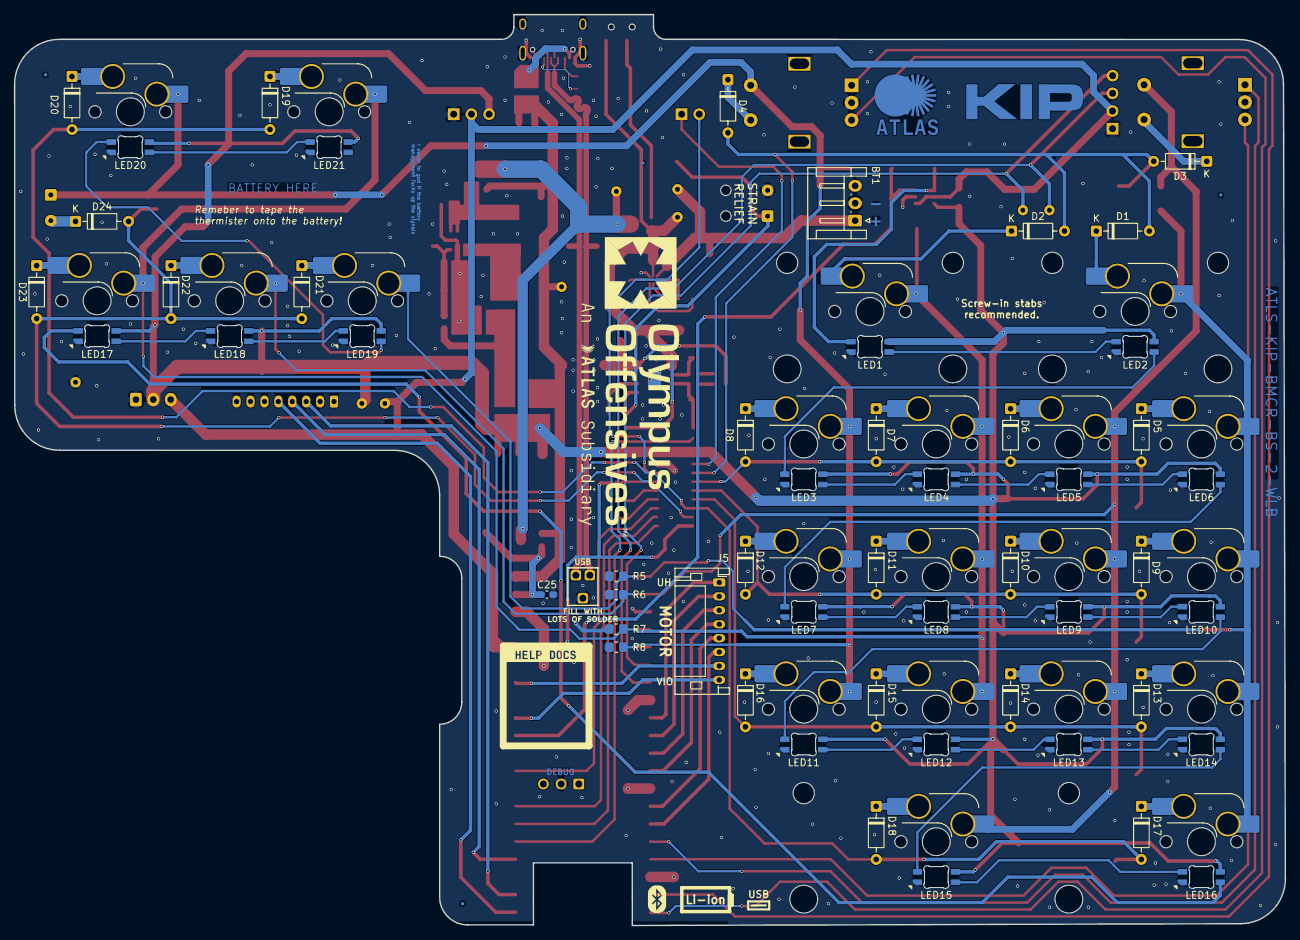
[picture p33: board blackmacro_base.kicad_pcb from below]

Board: 2 copper layers, 182.6 x 130.9 mm, 173 parts (53 on the bottom side), 110 nets.

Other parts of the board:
kibuzzard-6A2FA9C2: G***; kibuzzard-6A2FA9C2
kibuzzard-6A574CAA: G***; kibuzzard-6A574CAA

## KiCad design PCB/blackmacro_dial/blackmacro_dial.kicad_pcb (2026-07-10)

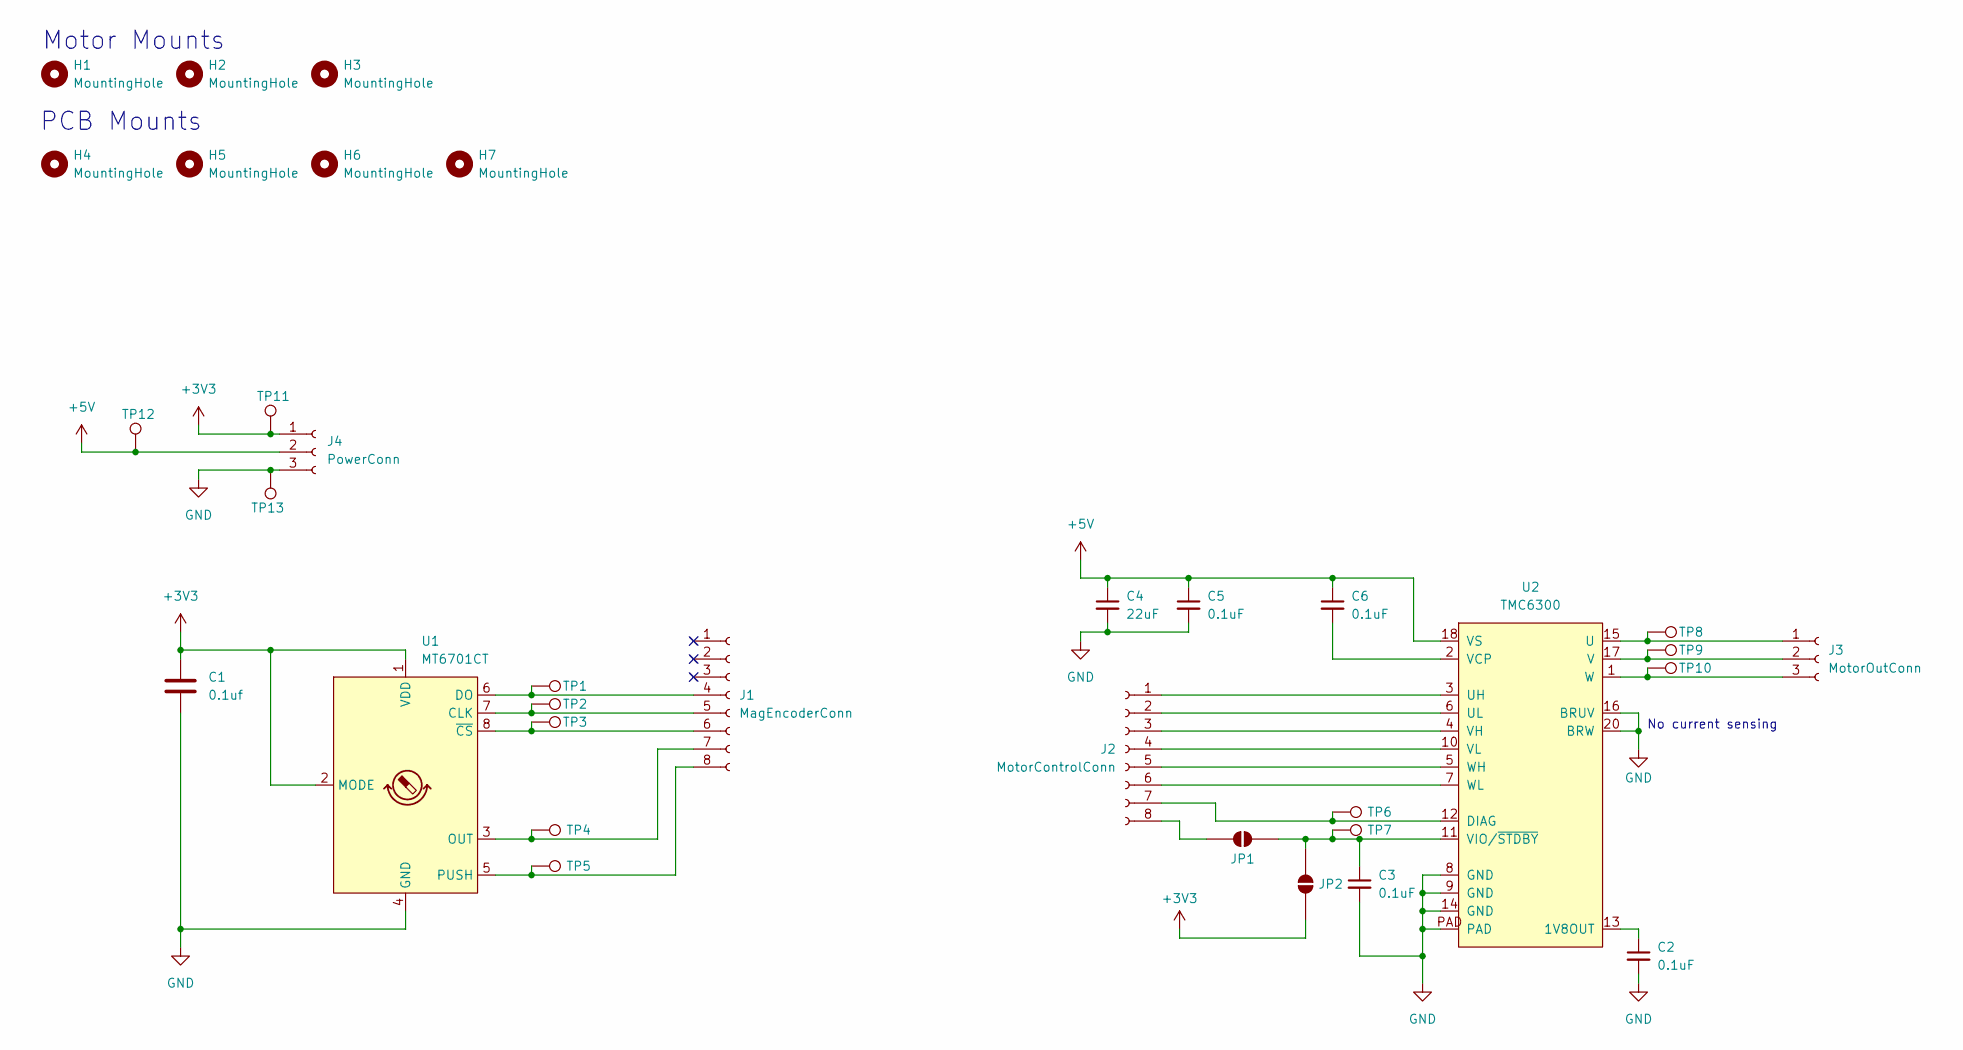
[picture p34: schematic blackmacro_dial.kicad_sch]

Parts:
C1: 0.1uf; C_1206_3216Metric_Pad1.33x1.80mm_HandSolder
C2, C3, C5, C6: 0.1uF; C_1206_3216Metric_Pad1.33x1.80mm_HandSolder
C4: 22uF; C_1210_3225Metric_Pad1.33x2.70mm_HandSolder
H1, H2, H3: MountingHole; MountingHole_2.2mm_M2_Pad_TopBottom
H4, H5, H6, H7: MountingHole; MountingHole_2.2mm_M2_Pad
J1: MagEncoderConn; JST_PH_S8B-PH-K_1x08_P2.00mm_Horizontal
J2: MotorControlConn; JST_PH_S8B-PH-K_1x08_P2.00mm_Horizontal; LCSC C20598766
J3: MotorOutConn; JST_EH_S3B-EH_1x03_P2.50mm_Horizontal; LCSC C22382557
J4: PowerConn; JST_EH_S3B-EH_1x03_P2.50mm_Horizontal; LCSC C22382557
JP1: SolderJumper_2_Bridged; SolderJumper-2_P1.3mm_Open_TrianglePad1.0x1.5mm
JP2: SolderJumper_2_Open; SolderJumper-2_P1.3mm_Open_TrianglePad1.0x1.5mm
TP1: MagEnc A; TestPoint_THTPad_D2.0mm_Drill1.0mm
TP2: MagEnc B; TestPoint_THTPad_D2.0mm_Drill1.0mm
TP3: MagEnc Z; TestPoint_THTPad_D2.0mm_Drill1.0mm
TP4: MagEnc Out; TestPoint_THTPad_D2.0mm_Drill1.0mm
TP5: MagEnc Push; TestPoint_THTPad_D2.0mm_Drill1.0mm
TP6: Motor Diagnostics; TestPoint_THTPad_D2.0mm_Drill1.0mm
TP7: Motor VIO; TestPoint_THTPad_D2.0mm_Drill1.0mm
TP8: Motor Out U; TestPoint_THTPad_D2.0mm_Drill1.0mm
TP9: Motor Out V; TestPoint_THTPad_D2.0mm_Drill1.0mm
TP10: Motor Out W; TestPoint_THTPad_D2.0mm_Drill1.0mm
TP11: 3V3; TestPoint_THTPad_D2.0mm_Drill1.0mm
TP12: 5V; TestPoint_THTPad_D2.0mm_Drill1.0mm
TP13: GND; TestPoint_THTPad_D2.0mm_Drill1.0mm
U1: MT6701CT; SO-8_3.9x4.9mm_P1.27mm
U2: TMC6300; QFN-20-1EP_3x3mm_P0.4mm_EP1.65x1.65mm_ThermalVias_LargerVia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

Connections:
+3V3: C1.1, J4.1, JP2.1 (A), TP11.1 (1_1), U1.1 (VDD), U1.2 (MODE)
+5V: C4.1, C5.1, C6.1, J4.2, TP12.1 (1_1), U2.18 (VS)
GND: C1.2, C2.2, C3.2, C4.2, C5.2, J4.3, TP13.1 (1_1), U1.4 (GND), U2.8 (GND), U2.9 (GND), U2.14 (GND), U2.16 (BRUV), U2.20 (BRW), U2.PAD
unnamed: J1.4, TP1.1 (1_1), U1.6 (DO)
unnamed: J1.5, TP2.1 (1_1), U1.7 (CLK)
unnamed: J1.6, TP3.1 (1_1), U1.8 (~CS)
unnamed: J1.7, TP4.1 (1_1), U1.3 (OUT)
unnamed: J1.8, TP5.1 (1_1), U1.5 (PUSH)
unnamed: J2.1, U2.3 (UH)
unnamed: J2.2, U2.6 (UL)
unnamed: J2.3, U2.4 (VH)
unnamed: J2.4, U2.10 (VL)
unnamed: J2.5, U2.5 (WH)
unnamed: J2.6, U2.7 (WL)
unnamed: J2.7, TP6.1 (1_1), U2.12 (DIAG)
unnamed: J2.8, JP1.1 (A)
unnamed: J3.1, TP8.1 (1_1), U2.15 (U)
unnamed: J3.2, TP9.1 (1_1), U2.17 (V)
unnamed: J3.3, TP10.1 (1_1), U2.1 (W)
unnamed: C3.1, JP1.2 (B), JP2.2 (B), TP7.1 (1_1), U2.11 (VIO/~STDBY)
unnamed: C2.1, U2.13 (1V8OUT)
unnamed: C6.2, U2.2 (VCP)

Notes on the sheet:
Motor Mounts
No current sensing
PCB Mounts

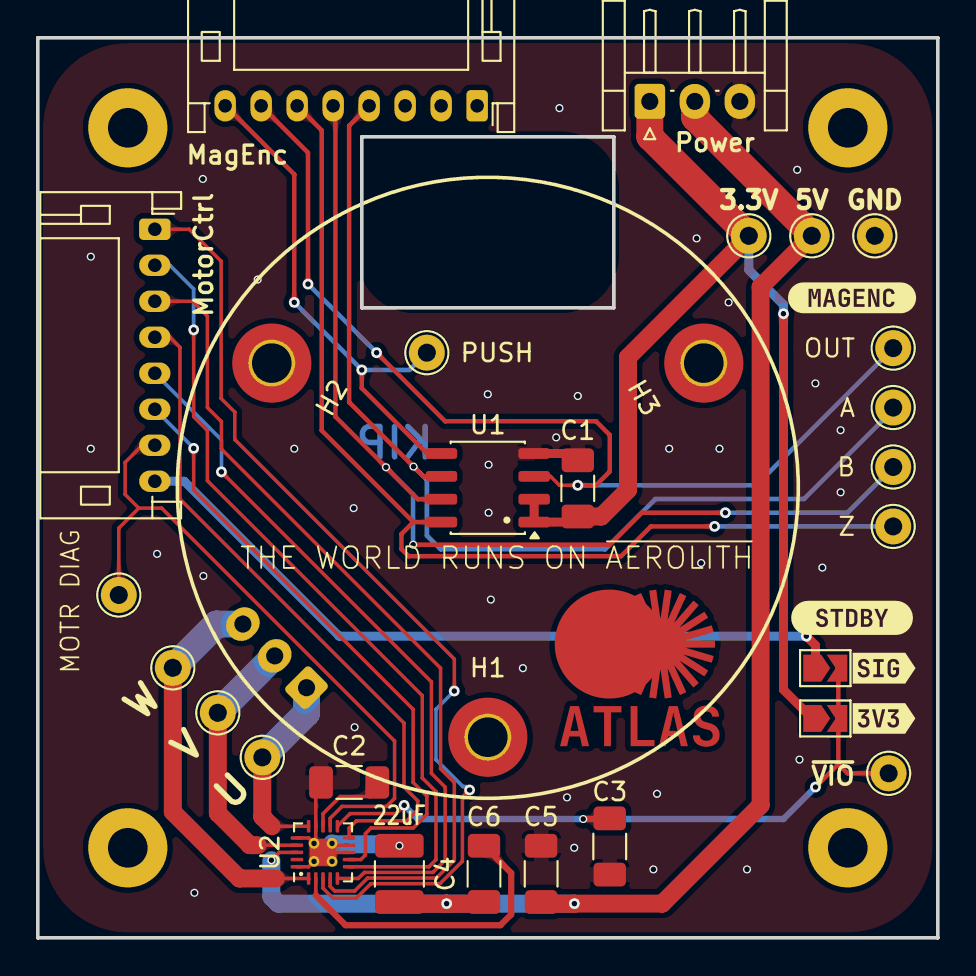
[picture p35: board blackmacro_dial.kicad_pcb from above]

Board: 2 copper layers, 50.0 x 50.0 mm, 38 parts (1 on the bottom side), 22 nets.

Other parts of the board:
kibuzzard-6A1DA964: G***; kibuzzard-6A1DA964
kibuzzard-6A1DAA49: G***; kibuzzard-6A1DAA49
kibuzzard-6A1DAA68: G***; kibuzzard-6A1DAA68
kibuzzard-6A1DB9AB: G***; kibuzzard-6A1DB9AB

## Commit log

2026-06-16 fix fix git
    [BOM.csv, Bmacro_Base_V1_5-FAB1_2026-06-15_bom.csv, Bmacro_Base_V1_5-FAB1_2026-06-15_designators.csv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]
2026-06-25 commit before switching to v2
2026-06-25 v2 switch
2026-06-25 updated pico footprint for pcb usb connections
    [blackmacro_base.kicad_pcb, blackmacro_base.kicad_sch]
2026-06-27 switched to pcb usb socket, battery management wip switched to pouch instead of 16850 pcb ready for rewiring + keyboard adjustments
    [blackmacro_base.kicad_pcb, blackmacro_base.kicad_sch]
2026-06-28 just the schottky diode left.... the BOM has now grown to 100 cny.... man this thing is gonna be expensive...
    [blackmacro_base.kicad_sch]
2026-07-10 schematics done, working on pcb
    [blackmacro_base.kicad_pcb, blackmacro_base.kicad_sch, blackmacro_dial.kicad_pcb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]
2026-07-14 everything routed except led
    [blackmacro_base.kicad_pcb, blackmacro_base.kicad_sch]
2026-07-15 before ground pour
    [blackmacro_base.kicad_pcb, blackmacro_base.kicad_sch]
2026-07-15 copper done todo: silkscreen + art
    [blackmacro_base.kicad_pcb, blackmacro_base.kicad_sch]
2026-07-15 v2 base done drc passed, basic check done
    [blackmacro_base.kicad_pcb]
2026-07-15 6-2-fab1
    do not use! (changed via dimensions to fit jlc's free tier)
    [Bmacro_Base_V1_5-FAB1_2026-06-15_positions.csv, Bmacro_Base_V2_6-2-FAB1_2026-07-15_bom.csv, Bmacro_Base_V2_6-2-FAB1_2026-07-15_designators.csv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]
2026-07-16 7-2-fab1, archive before switching to 8-2-fab1 (changed via diameters for cheaper tier, next change is changing bga diameter to 0.25 so i can use hasl)
    [Bmacro_Base_V2_7-2-FAB1_2026-07-15_bom.csv, Bmacro_Base_V2_7-2-FAB1_2026-07-15_designators.csv, Bmacro_Base_V2_7-2-FAB1_2026-07-15_positions.csv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]
2026-07-23 10-2-fab1 the production version. project files have already been updated to 11-2-fab2, with critical fixes with the logic shifter (incorrect schematics in 10-2-fab1).
    this commit is mostly to archive the production files, please use 11-2-fab2.
    [Bmacro_Base_V2_10-2-FAB1_2026-07-17_bom.csv, Bmacro_Base_V2_10-2-FAB1_2026-07-17_designators.csv, Bmacro_Base_V2_10-2-FAB1_2026-07-17_positions.csv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]
2026-07-23 2-11-fab2 plus readme
    [Bmacro_Base_V2_11-2-FAB2_2026-07-23_bom.csv, Bmacro_Base_V2_11-2-FAB2_2026-07-23_designators.csv, Bmacro_Base_V2_11-2-FAB2_2026-07-23_positions.csv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]
2026-08-07 V2 pre-release BOM not done, updating gitignore to remove keebio-parts
    [Bmacro_Base_V2_11-2-FAB2_2026-07-23_bom.csv, Bmacro_Base_V2_11-2-FAB2_2026-07-23_designators.csv, Bmacro_Base_V2_11-2-FAB2_2026-07-23_positions.csv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]
2026-08-07 V2 add plate
    [Assembly V2.f3z, Bmacro_Base_V2_12-2-FAB2_2026-07-24_bom.csv, Bmacro_Base_V2_12-2-FAB2_2026-07-24_designators.csv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]
2026-08-07 Finished full BOM
    [Case Bottom.3mf, Jog Wheel.3mf, Jog Wheel.f3d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]
2026-08-07 change to lfs
    [Case Bottom.step, Case Top.step, Jog Wheel.step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]
2026-08-09 modify switch for resin printing, jog wheel for cnc, finished promo art
    [Jog Wheel.step, Jog Wheel_divet.3mf, Switch.3mf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]
2026-08-10 updated bom with cnc costs
    [BOM.csv, bom_case.csv]

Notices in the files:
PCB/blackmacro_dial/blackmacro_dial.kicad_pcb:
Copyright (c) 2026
